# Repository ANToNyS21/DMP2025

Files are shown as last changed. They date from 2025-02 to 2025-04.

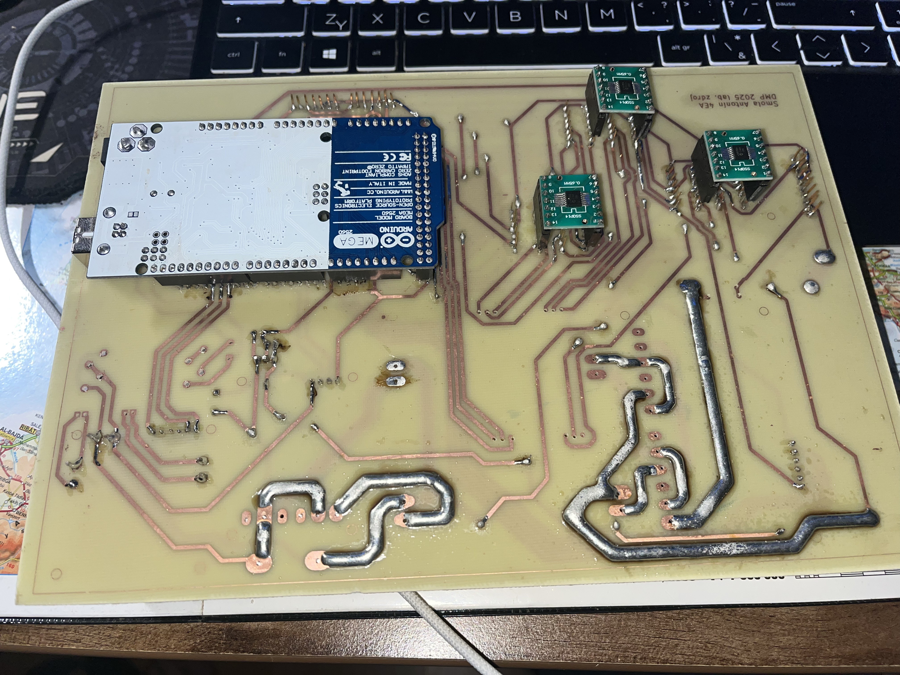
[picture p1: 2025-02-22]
smolaan21/media/DPS_testování_DCP2.JPG

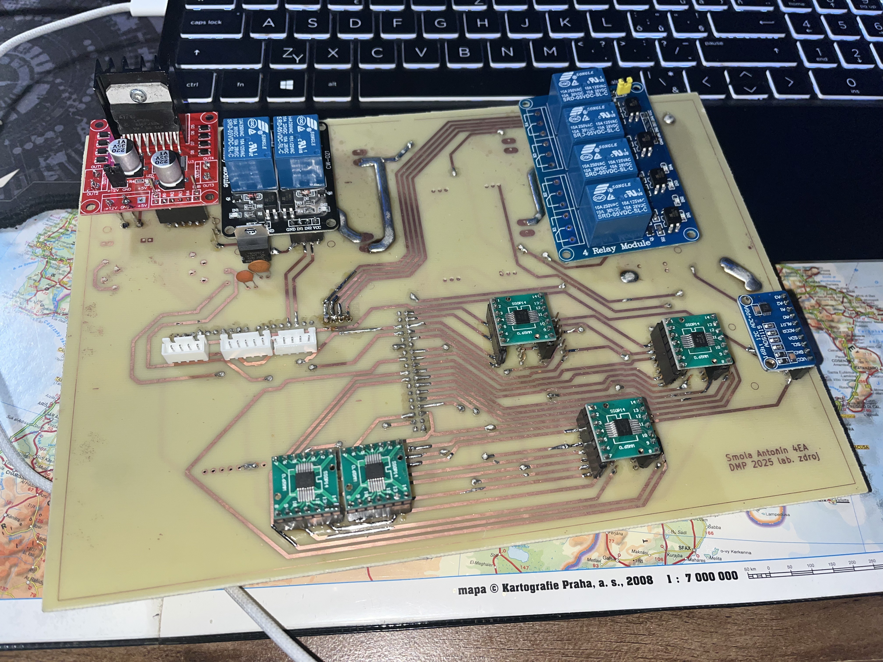
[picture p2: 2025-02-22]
smolaan21/media/DPS_testování_DCP1.JPG

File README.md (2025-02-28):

# DMP2025
sestava na ONSHAPE : https://cad.onshape.com/documents/a55f27827d7d0bf78ad17041/w/e62290534607ad3c1cca5b53/e/726e90d26969cd6e7ac2d84b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

video s funkčností / ukázkou menu:

https://drive.google.com/file/d/1NYgzzBReGRTbW6AwwNUOp2N6VFr0sSx1/view?usp=sharing

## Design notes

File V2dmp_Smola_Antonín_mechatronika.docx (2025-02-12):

Dlouhodobá maturitní práce

26-41-M/01 Elektrotechnika

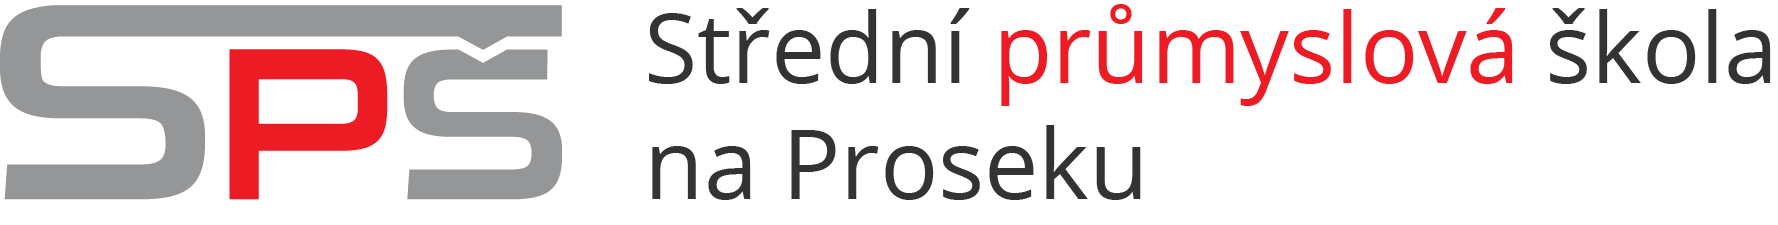
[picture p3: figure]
Logo

Laboratorní zdroj

Smola Antonín

Vedoucí: Jan Kárník

Zaměření: Mechatronika

2025

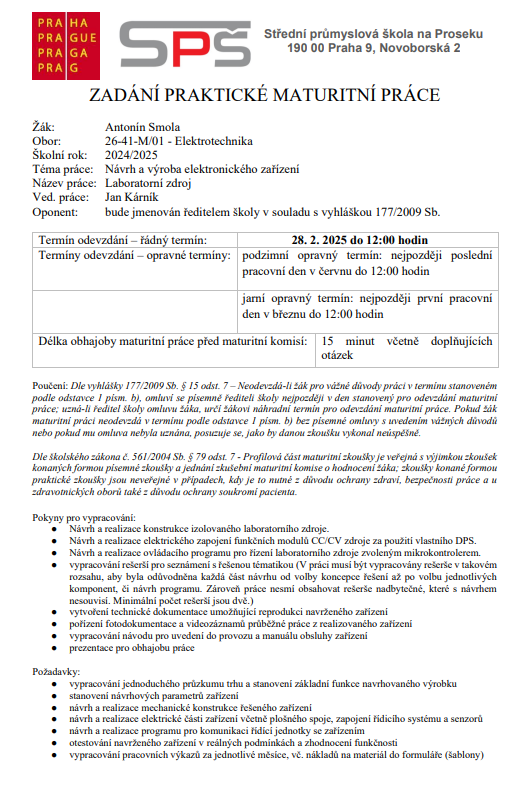
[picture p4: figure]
Obsah obrázku text, snímek obrazovky, Písmo, dopis Popis byl vytvořen automaticky
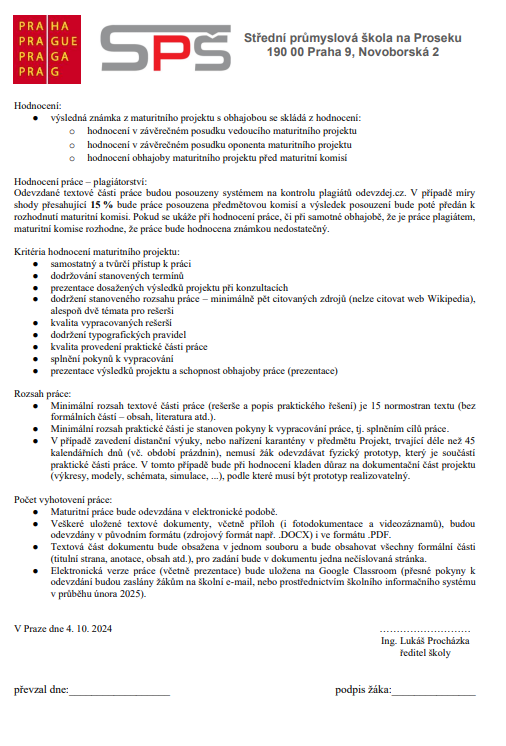
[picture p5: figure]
Obsah obrázku text, snímek obrazovky, dokument, dopis Popis byl vytvořen automaticky

# Prohlášení

Prohlašuji, že jsem svou maturitní práci vypracoval samostatně a že jsem uvedl veškeré použité informační zdroje (literaturu, projekty, SW, atd.), které jsou uvedené v seznamu literatury.

Nemám závažný důvod proti užití tohoto školního díla ve smyslu § 60 zákona č. 121/2000 Sb., o právu autorském, o právech souvisejících s právem autorským a o změně některých zákonů (autorský zákon).

V Praze, 2025

……………………………………

Podpis autora práce

# Poděkování

Tímto bych rád poděkoval svým rodičům, kteří byli mou oporou při tvorbě dlouhodobé maturitní práce, po fyzické a abstraktní stránce. Rád bych také poděkoval všem učitelům, kteří mi s touto prací byly nápomocni a ochotni konzultovat problémy, spojené s touto prací, které jsem musel řešit .

# Abstrakt

CZ verze

# Abstract

EN verze

# Obsah

# Seznam obrázků

# Seznam tabulek

# Úvod

Cílem práce je návrh a realizace digitalizace laboratorního zdoje. Tohoto cíle chci dosáhnout výměnou stávajících potenciometrů na modulu CC a CV za obvody, které převedou digitální výstup z mikrokontroleru, pomocí DA převodníků a operačních zesilovačů, na napětí které bude použito jako referenční napětí na modulu CC, CV.

V poslední době jsem se začal zajímat o funkcionalitu laboratorních zdrojů, protože po koupi komerčně dostupného laboratorního zdroje jsem se jím rychle stal fascinován. Na tomto zdroji mi ale nevyhovuje uživatelské rozhraní v podobě dvou potenciometrů a špatně nečitelného displeje. Chtěl bych tyto chyby opravit ve své práci v podobě enkodérů jako uživatelské rozhraní a 20x4 LCD displejem.

Práce se bude skládat ze základní dekonstrukce laboratorního zdroje, pochopení funkcionality modulu CC a CV, vybrání nejoptimálnější digitalizační metody, návrh DPS, návrh schránky pro zdroj.

# Rešerše

(1)(2)(3)(4)(5)(6)(7)(8)(9)(10)(11)(12)(13)(14)(15)(16)

## 1.1 „Digitalizace“ potenciometrů

Na modulech CC a CV jsou 2 potenciometry o hodnotách 2KΩ, na nastavení výstupního proudu, a 50KΩ na nastavení výstupního napětí. Ty bych chtěl nahradit/upravit tak, aby šlo moduly ovládat přes enkodéry a mikrokontroler. Tuto rešerši jsem tedy věnoval vhodné náhražce 2 potenciometrů.

### 1.1.1 Digitální potenciometr (Digitally controlled potentiometer, DCP)

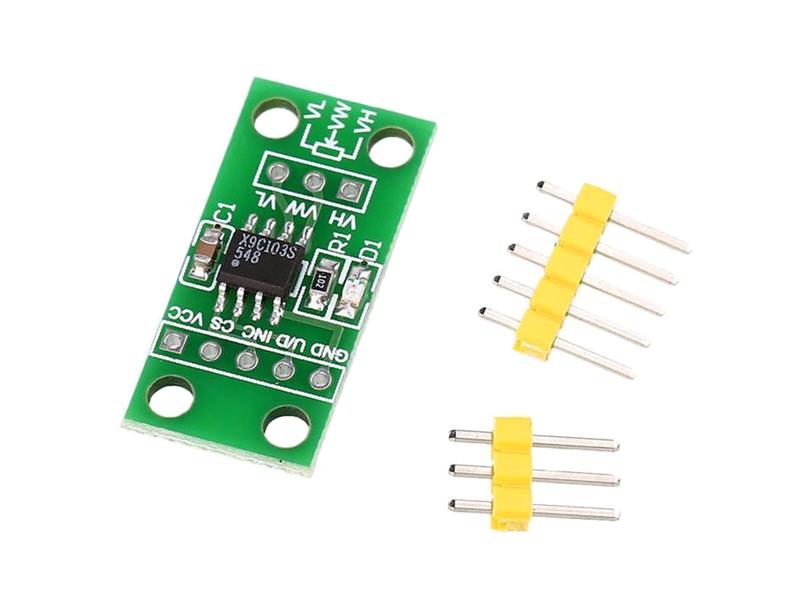
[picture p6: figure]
Digitální potenciometr 10kohm, modul s X9C103S

Popis: Digitální potenciometr (Obrázek 1), často označovaný jako DCP, funguje jako náhrada klasického mechanického potenciometru, ale místo manuálního otáčení rotační hřídelí je odpor nastavován pomocí digitálních signálů na logických úrovních. Tento typ potenciometru využívá pevný rezistorový řetězec a elektronické přepínače, které selektivně propojují různé body na řetězci, tudíž na výstupu vzniká různý výsledný odpor.

Obrázek 1 – příklad DCP [1]

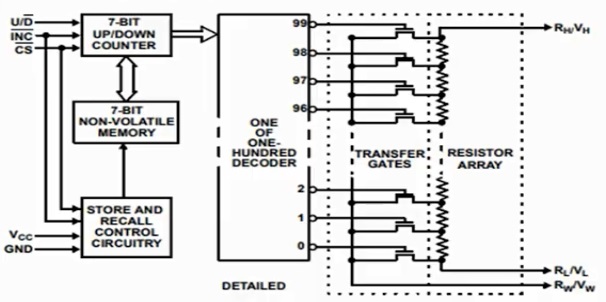
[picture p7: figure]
digital potentiometer x9c103s

Fungování: Ovládání digitálních potenciometrů probíhá prostřednictvím komunikačních protokolů, jako jsou I2C a SPI. Z mikrokontroleru se po sběrnici odešle v požadovaném formátu, daným výrobcem DCP, informace o požadovaném počtu do série spojených pevných rezistorů(Obrázek 2Chyba! Nenalezen zdroj odkazů.). Mikrokontroler na DCP poté informace přijme, vyhodnotí a provede potřebné kroky pro splnění přijatých požadavků.

Obrázek 2 - vnitřní schema DCP [2]

Příklady použití: Digitální potenciometry lze využit, například při řízení hlasitosti ve zvukových systémech, nastavování napěťového offsetu, ladění frekvenčních filtrů nebo jako náhrada potenciometrů v určitých aplikací.

Výhody: Umožňuje přesné, rychlé řízení výstupu bez mechanického opotřebení a snadná integrace do digitálně řízených systémů.

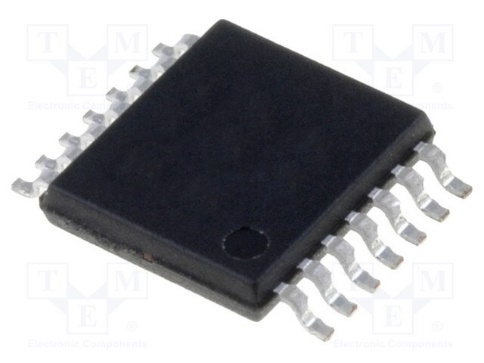
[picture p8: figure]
MICROCHIP TECHNOLOGY MCP41HV51-103E/ST - IC: číslicový potenciometr

Nevýhody: Nižší maximální výkony (např. některé jsou omezené na napětí v řádu několika mW výkonu nebo desítek mA proudu) a nižší maximální napětí.

Příklady součástek:

- MCP41010 (od Microchip, SPI rozhraní)
- MCP41HV51 (Obrázek 3) (od Microchip, SPI rozhraní)
- AD5252 (od Analog Devices, I2C rozhraní)

Obrázek 3 - MCP41HV51 [3]

### 1.1.2 Digitálně ovládané tranzistory (MOSFET)

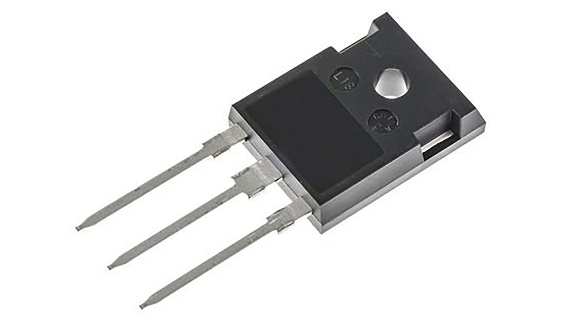
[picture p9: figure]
MOSFET C2M1000170D N-kanálový 5 A 1700 V, TO-247, počet kolíků: 3 Jednoduchý SiC

Popis: Tranzistory MOSFET (Obrázek 4) mohou regulovat proud a napětí pomocí pulzní šířkové modulace (PWM), kterou lze ovládat pomocí mikrokontroleru.

Fungování: Průměrné výstupní napětí nebo proud lze řídit PWM signálem, jehož frekvence a střída určuje hodnotu výstupního signálu. PWM signál vytváří zátěž, která prochází tranzistorem, čímž se mění průměrné napětí.

Obrázek 4 – MOSFET [4]

Výhody: Vysoká účinnost.

Nevýhody: Složitější implementace a požadavek na vyhlazovací obvody a neschopnost plynulé regulace (bez vyhlazovacího obvodu na výstupu skoky napětí)

### 1.1.3 Digitální řízení přes DAC (Digital-to-Analog Converter)

Popis: DAC převádí digitální hodnoty z mikrokontroléru na čisté analogové napětí. To nahrazuje funkci potenciometru pro jemné nastavování referenčního napětí či proudového řízení.

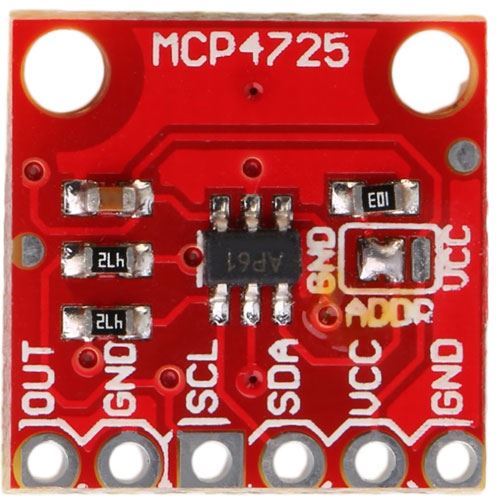
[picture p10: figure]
DAC převodník 12Bit I2C s MCP4725 : H A D E X , spol. s r.o.

Fungování: Mikrokontrolér posílá digitální data do DAC, který je převádí na analogové napětí.

Obrázek 5 - MCP4725 [5]

Výhody: Vysoká přesnost, široký rozsah aplikací.

Nevýhody: Vyšší náklady a složitost v porovnání s digitálním potenciometrem.

Příklady DAC:

- MCP4725 (Obrázek 5) (jednokanálový, I2C rozhraní)
- AD5686 (čtyřkanálový, SPI rozhraní)

### 1.1.4 Přímé řízení pomocí PWM a nízkoprůchodového filtru

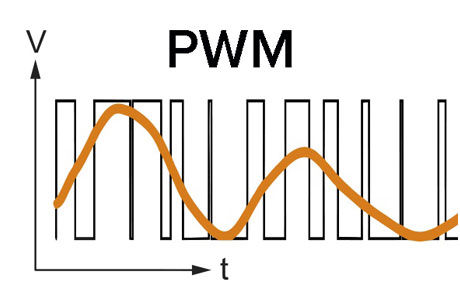
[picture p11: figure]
What Is PWM (Pulse Width Modulation)? | IndMALL

Popis: Alternativním způsobem pro dosažení analogového výstupního napětí je použití PWM signálu z mikrokontroléru. Tento signál je filtrován pomocí nízkoprůchodového filtru, který vyhlazuje výstup na plynulý analogový signál.

Obrázek 6 – PWM [6]

Fungování: PWM signál prochází nízkoprůchodovým filtrem, který eliminuje vyšší frekvence a zachovává průměrnou hodnotu signálu (Obrázek 6). To umožňuje převod PWM signálu na přijatelný analogový.

Výhody: Snadná integrace s Arduino a jinými mikrokontroléry.

Nevýhody: Nutnost navrhnout vhodný filtr a nižší přesnost ve srovnání s DAC nebo digitálním potenciometrem, vysoké proudové zatížení mikrokontroleru.

### 1.1.5 Závěr rešerše a moje volba

Pro mojí aplikaci na modulech CC a CV jsem si vybral požít digitální potenciometry MCP41HV51 (od Microchip, SPI rozhraní), protože přímo nahradí potenciometr bez nutnosti použití složitých obvodů na ovládáni např. DAC a operačních zesilovačů. Nevýhodou jsou fixní hodnoty možného odporu v mém případě MCP41HV51 je 8 bitový digitální potenciometr s 256 možnými hodnotami odporu.

## 1.2 Měření proudu na výstupu zdroje

V mém projektu potřebuji na výstupu zdroje měřit výstupní proud, jehož hodnotu potřebuji zobrazovat na displeji. Potřebuji tedy nějakou metodu, která dokáže změřit proud a odeslat jeho hodnotu do mikrokontroleru.

### 1.2.1 Měření proudu pomocí shunt rezistoru

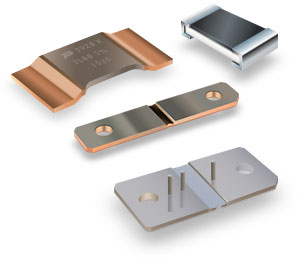
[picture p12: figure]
prodline_current_sense_resistors_lg

Jednou z nejběžnějších metod měření proudu je použití shunt rezistoru (Obrázek 7). Tato metoda je založena na Ohmově zákonu, který říká, že proud (I) je přímo úměrný napětí (U) a nepřímo úměrný odporu (R), tedy

Obrázek 7 - Shunt rezistor [7]

| I=U/R | (2.1)

V tomto případě je malý odpor (shunt rezistor např. 1Ω) vložen do série s obvodem, ve kterém chceme měřit proud. Napěťový úbytek na tomto odporu je měřen pomocí ADC (analogově-digitálního převodníku) a následně odeslán do mikrokontroleru.

Výhody: Jednoduché zapojení, přesné přímé měření, široký rozsah měření při různých hodnotách proudu.

Nevýhody: Shunt rezistor způsobuje úbytek napětí v obvodu, zahřívání rezistoru při vyšších proudech může ovlivnit přesnost měření, nutnost používat výkonové shunt rezistory

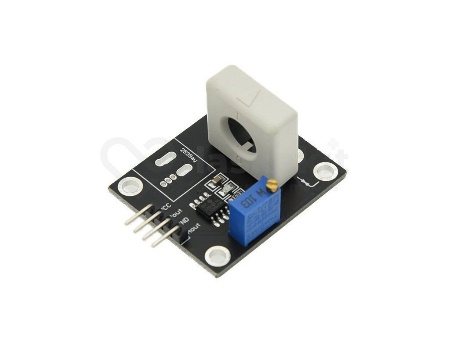
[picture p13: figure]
Hallův neinvazivní snímač proudu WCS1800-35A

### 1.2.2 Hallův efekt

Měření proudu pomocí Hallova efektu je nepřímá metoda, která využívá vlivu magnetického pole na polovodičový materiál. Když proud prochází vodičem, vytváří kolem něj magnetické pole. Hallův snímač (Obrázek 8) umístěný v blízkosti vodiče měří toto pole.

Obrázek 8 - Hallův snímač proudu [8]

Výhody: Nepřímé bezpečné měření, protože není třeba zasahovat přímo do obvodu, žádné úbytky napětí v měřeném obvodu, vhodné pro měření jak stejnosměrného (DC), tak střídavého (AC) proudu.

Nevýhody: Nižší přesnost než u přímých metod, vyšší cena snímačů, citlivost na vnější magnetická pole, což může způsobit rušení.

### 1.2.3 Transformátor proudu

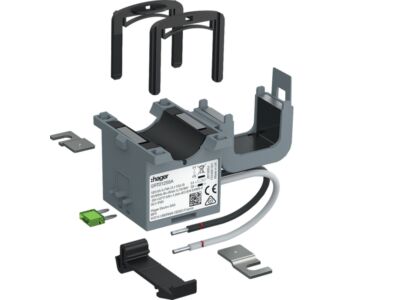
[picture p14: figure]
Proudový transformátor s děleným jádrem

Transformátory proudu (CT, Current Transformer,Obrázek 9) jsou speciální typy transformátorů určené pro měření vysokých proudů ve střídavých obvodech. Primární vinutí transformátoru je vodič s měřeným proudem, zatímco sekundární vinutí je připojeno k měřicímu přístroji, kde proud snížený poměrem transformace může být bezpečně měřen AD převodníkem.

Obrázek 9 - proudový transformátor [9]

Výhody: Možnost měřit vysoké proudy, elektrické oddělení mezi primární a sekundární stranou, široký rozsah měření.s

Nevýhody: Použitelné pouze pro střídavé proudy, vyžaduje přesnou kalibraci, aby byla zachována přesnost, složitější mechanická konstrukce.

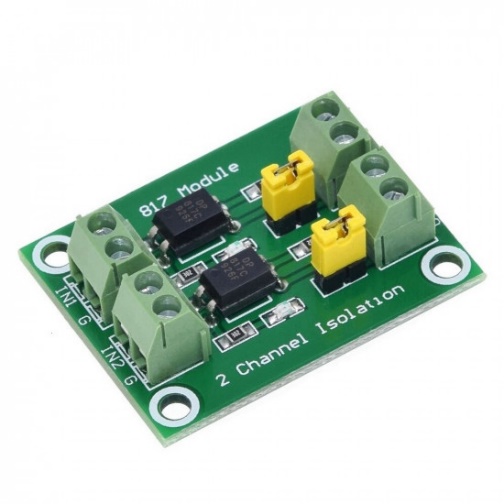
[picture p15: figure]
Dvoukanálový modul optoizolátoru s PC817

### 1.2.4 Měření proudů pomocí optoizolátorů

Optoizolátory (Obrázek 10) se často používají k měření proudu v prostředích, kde je třeba galvanické oddělení. Tento princip zahrnuje použití LED a fotodetektoru – proud protékající obvodem způsobí, že LED emituje světlo, které je detekováno fotodetektorem a převedeno na elektrický signál úměrný proudu.

Výhody: Úplné galvanické oddělení mezi měřeným obvodem a měřicím zařízením, vysoká bezpečnost při měření vysokých proudů nebo napětí.

Obrázek 10 - dvoukanálový optoizolátor [10]

Nevýhody: Komplexní elektronika potřebná pro zpracování signálu, omezený rozsah a přesnost měření.

## 1.3 Závěr rešerše a moje volba

Pro moji aplikaci nemohu použít metody pro měření proudů v AC obvodu bez dalších DC to AC převodníků, proto Transformátor proudu nelze použít. Vzhledem k nízkým měřeným proudům a možnosti rušení Hallova sensoru díky kompaktním požadavkům laboratorního zdroje. Pro moji aplikaci tedy použiji metodu Shunt rezistoru a AD převodníku, protože v kombinaci s 12bitovým AD převodníkem, dokáži dosáhnou velmi přesného měření proudu s minimální nepřesností díky přímému měření proudu, které tato metoda zahrnuje.

# Návrhové parametry

Laboratorní zdroj s CC a CV (dále jen „Laboratorní zdroj“) bude konstruován jako relativně přenosný (bez madel, pouze jeho rozměry a váha by měly umožnit jeho přesun) a s elektricky izolovanými výstupy od přívodního AC napětí. Laboratorní zdroj bude mít v zadní části konektor 3 Pin IEC320 C14 s integrovaným kolébkovým vypínačem a pojistkou. Všechny kovové části zdroje budou elektricky spojeny s ochranným vodičem (PE). Zdroj bude na přední straně disponovat 3 výstupními terminály: MÍNUS, GND, PLUS (v tomto pořadí) (GND bude spojeno s PE ochranným vodičem), displejem a dvěma enkodéry jako uživatelské rozhraní.

Laboratorní zdroj bude na displeji zobrazovat aktuální výstupní napětí a výstupní proud zdroje, které se budou upravovat po stisku jednoho z enkodérů podle požadavků uživatele. Laboratorní zdroj bude schopen dodávat napětí až 30V a proud až 4A.

# Praktická část

V následujících kapitolách jsem se zaměřil na praktickou část DMP, zvažování možných řešení, odůvodnění mnou vybraného řešení a následné provedení tohoto řešení v praxi.

## 1.4 Elektrická část

### 1.4.1 CC a CV moduly

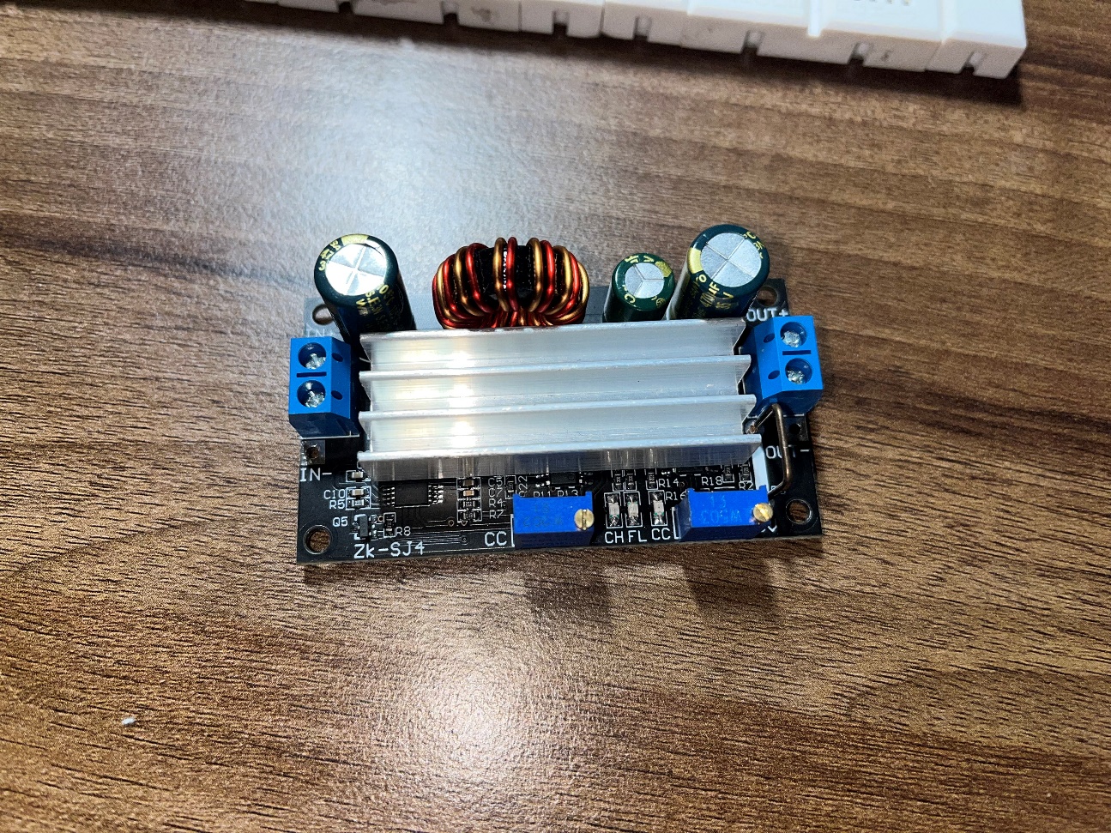
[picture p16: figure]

Hlavní částí mého maturitního projektu jsou dva zdroje napětí a proudu (Obrázek 11) s možností regulace těchto veličin podle polohy dvou trimerů. Trimer 50KΩ na regulaci výstupního napětí a trimer 2KΩ na regulaci výstupního proudu. Tyto trimery nahrazuji jejich digitálními variantami DCP (1.1.1).

Obrázek 11 - modul ZK-SJ4

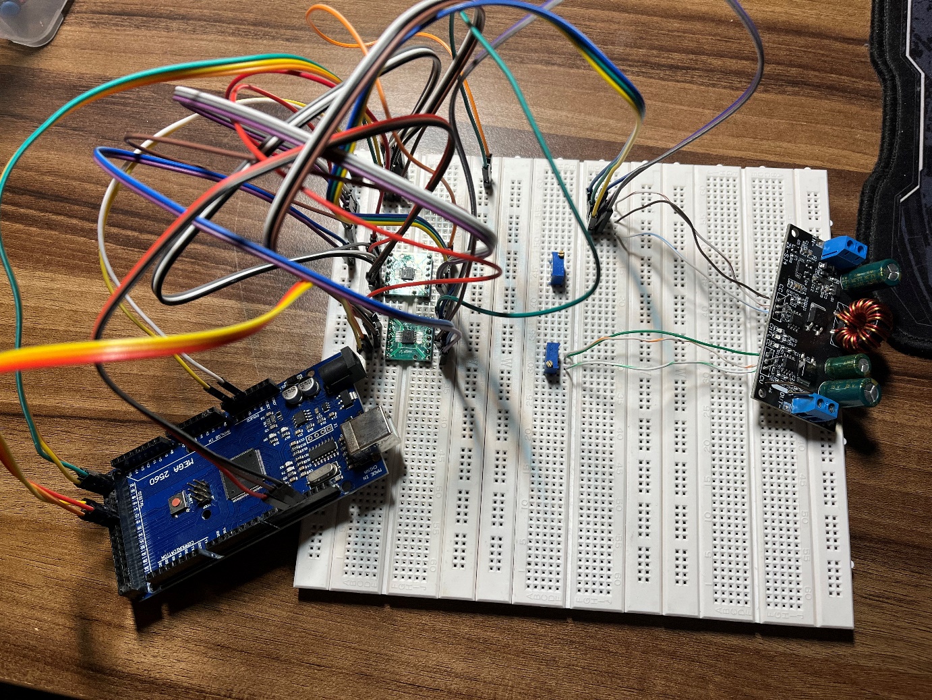
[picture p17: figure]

Pro usnadnění testovaní možných nahrazení trimerů jsem u modulu napětí a proudu odstranil oba trimery a nahradil je drátovými propojkami pro snadnou integraci do nepájivého pole (Obrázek 12).

Obrázek 12 - prototypové zapojí modulu s dvěma DCP

Jako první variantu jak ovládat proud a napětí modulů zdrojů jsem zkoušel využít DCP
X9C103S (Obrázek 1), který podle datasheatu ([14]) dokázal nastavit 100 různých hodnot odporu mezi jeho maximální a minimální, hodnotou podle následujícího vzorce

[3.1.1]

R_V =(R_(MAX))/100×STEP ,

Kde R_V představuje výstupní hodnotu odporu DCP, R_(MAX) maximální hodnotu odporu DCP a STEP představuje nastavený krok v celých číslech na DCP od 0 do 99.

Pomocí knihovny FastX9CXXX [12] poté DCP lze jednoduše ovládat a získat i přibližnou hodnotu výstupního odporu.

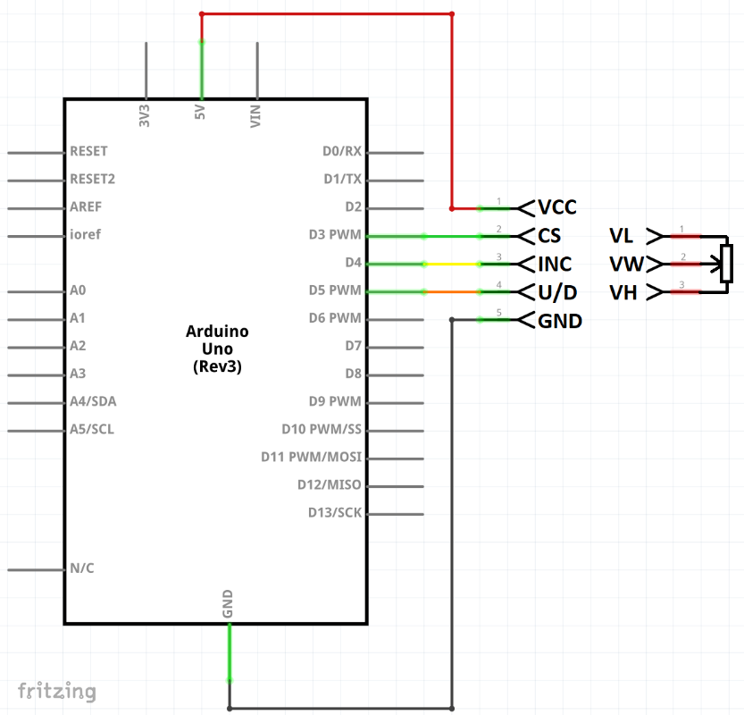
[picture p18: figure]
Digitální potenciometr X9C103S schéma

Tento způsob ovládání vyžaduje pouze 5 propojení DCP s mikrokontrolerem, přičemž piny 1 a 5 jsou použity pro napájení a zbylé piny 2, 3, 4 musí být připojeny na digitál out piny mikrokontroleru. Bohužel DCP X9C se vyrábí pouze ve variantách 1KΩ, 10kΩ,
100kΩ, což pro mé účely bylo značně nepraktické, protože pro docílení potřebného odporu by bylo zapotřebí využívat paralelního zapojení výstupů DCP pro dosáhnutí požadovaného odporu na výstupu.

Obrázek 13 - zapojení X9C102S s Arduinem UNO [11]

Další z problémů, kvůli kterému jsem se definitivně rozhodl toto řešení pomocí
DPC X9C zavrhnout, byla limitace napětí stanovená výrobcem [13], které může být od –8V do +8V mezi VL a VH (Obrázek 13). Toto byl zásadní parametr, protože moduly CC a CV mají na pinech trimerů napětí až +28V při maximálním zatížením. Z tohoto důvodu jsem jako jednu z hlavních kategorií pro výběr jiného DCP vybral maximální napětí na výstupních pinech.

Jako mé další a zároveň finální řešení řízení modulů CC a CV jsem zvolil použití DCP MCP41HVX1. Už z jejich názvu (HV- High Voltage) je patrná jejich hlavní výhoda a to maximální napětí na výstupních pinech až +36V nebo ±18V, což bylo ideální pro mou aplikaci +28V. Další výhodou těchto DCP je širší rozsah možných hodnot oproti 100 možných pozic MCP41HVX1 má 256 možných pozic.

Těchto 256 pozic navíc mi umožnilo ovládání napětí na přesnost 0,125V oproti předchozímu teoretickému 0,32V na jeden STEP podle rovnice

[3.1.2]

V_(STEP) =(V_(Max))/(STEPS) , kdy V_(STEP) je napětí na 1 krok, V_(Max) je maximální napětí modulu CC a CV, a STEPS je počet kroků DCP.

Bohužel ale MCP41HVX1 vyžaduje pro své ovládání využití SPI komunikačního protokolu a připojení 8mi pinu na mikrokontroler pro úspěšné ovládání. Navíc podle výrobce [15] MCP41HVX1 potřebuje pro svou správnou funkčnost ČÍSTÉ analogové napětí +30V, které musí být dodáno z externího zdroje. Naštěstí +30V je zapotřebí pouze jako reference pro funkčnost analogového obvodu v DCP a reálný odběr je okolo 8mA na modul DCP, proto stačí použít měkčí zdroj napětí.

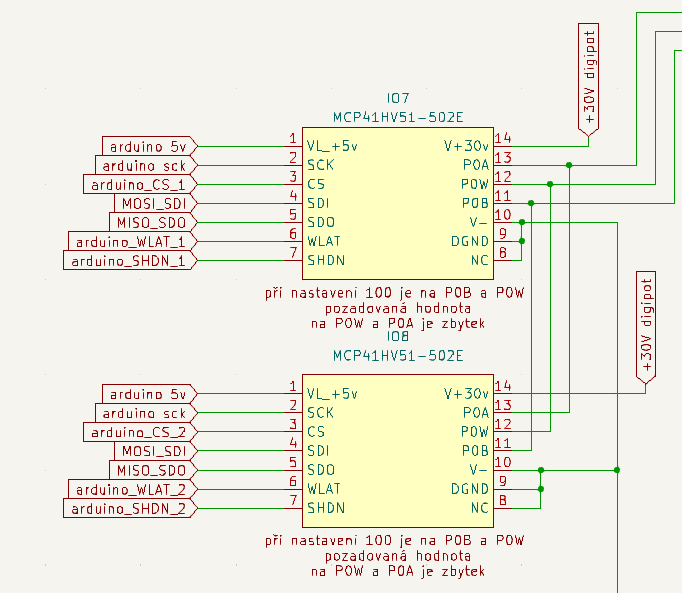
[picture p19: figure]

Pro mé účely jsem použil vždy pár MCP41HVX1 se stejnou hodnotou odporu zapojený do paralelního zapojení (Obrázek 14). Tímto zapojením jsem také docílil podle rovnice [3.1.2] až 32768 možných nastavení výstupního napětí modulů s přesností cca na 0,001V.

Obrázek 14 - zapojení MCP41HVX1

### 1.4.2 Schéma zapojeni

Mnou navržený obvod pro ovládání a propojení jednotlivých komponentů s mikrokontrolerem jde rozdělit na několik hlavních částí, jmenovitě na:

- Externí zdroj 12V
- On-board zdroje 5V a 36V
- Ovládání ventilátorů
- UI
- Měření výstupních veličin
- Jednotlivé CC a CV moduly a jejich DCP

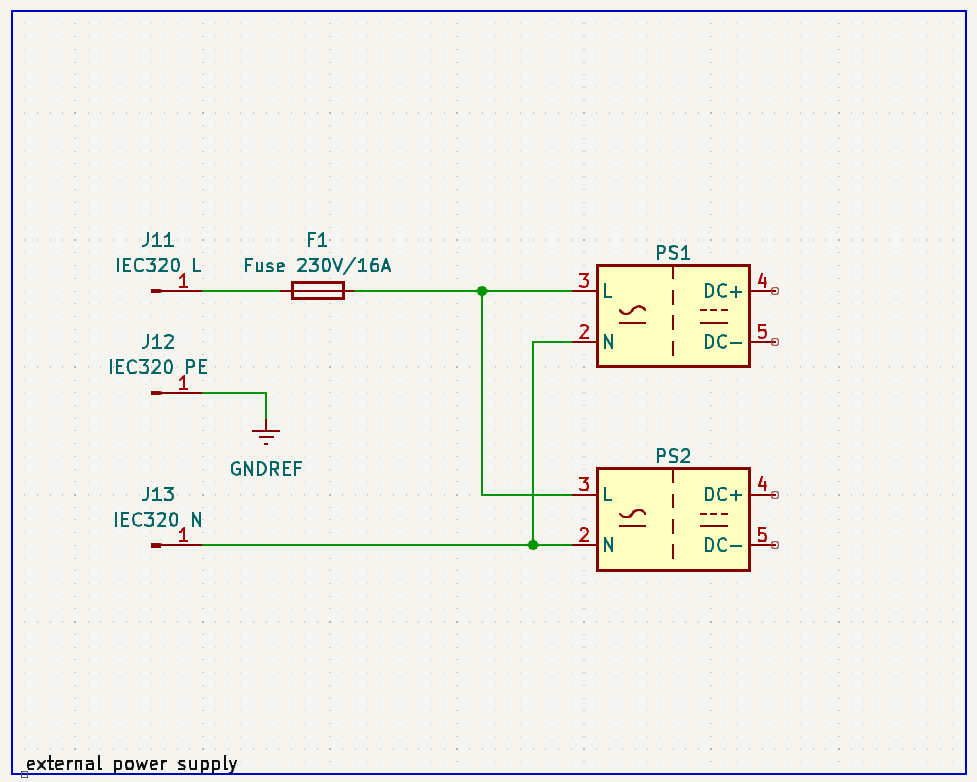
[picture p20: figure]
Obsah obrázku text, diagram, snímek obrazovky, Obdélník Obsah vygenerovaný umělou inteligencí může být nesprávný.

#### 1.4.2.1 Externí zdroj 12V

Obrázek 15 - 12v Power Supply

Pro hlavní napájení mého maturitního projektu jsem si vybral dva 250w zdroje z 230v AC na 12V DC (17). Pro přívod napájení do útrob maturitního projektu jsem vybral IEC320 C14 s integrovaným kolébkovým vypínačem a pojistkou, což řeší jištění systému a zároveň jeho zapínání a vypínání.

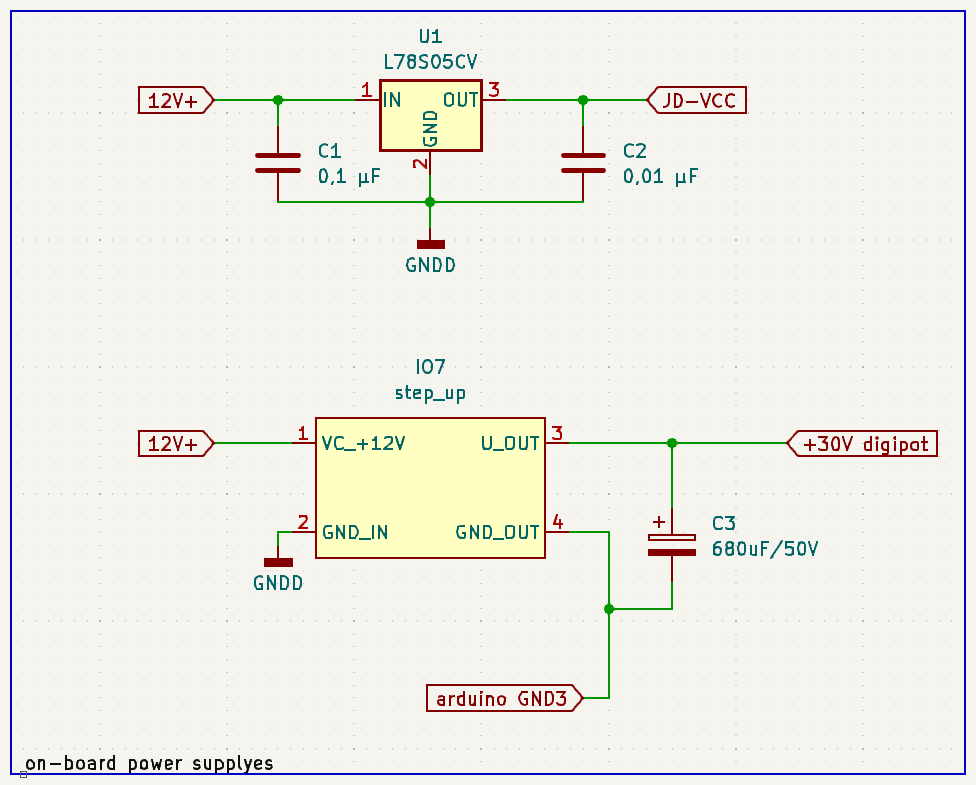
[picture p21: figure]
Obsah obrázku text, diagram, snímek obrazovky, Plán Obsah vygenerovaný umělou inteligencí může být nesprávný.

#### 1.4.2.2 On-board zdroje 5V a 36V

Obrázek 16 - On-board zdroje

Pro napájení relé logiky jsem vybral Linearní Stabilizátor napětí L78S05CV, který dokáže dodávat až 2A při 5V s použitím chladiče (18). V mém testovaní při sepnutí všech relé na DPS 5V obvod odebíral nejvíce 950mA, ale tento stav nemůže v reálnem provozu nikdy nastat z důvodu vzniku zkratu v obvodu. Nehledě na max. 950mA jsem L78S05CV vybavil chladičem a součástku umístil v průtoku vzduchu k ventilátoru pro zvýšení životnosti.

Pro napájení DCP analogových obvodů jsem vybral Modul DC/DC měnič step-up 5-40V/2A (19) s řídícím čipem LM2577. Tento měnič napájí jednotlivé DCP 32V. Jeho zatížení je při provozu prakticky nulové reálný odběr se pohybuje kolem 80mA.

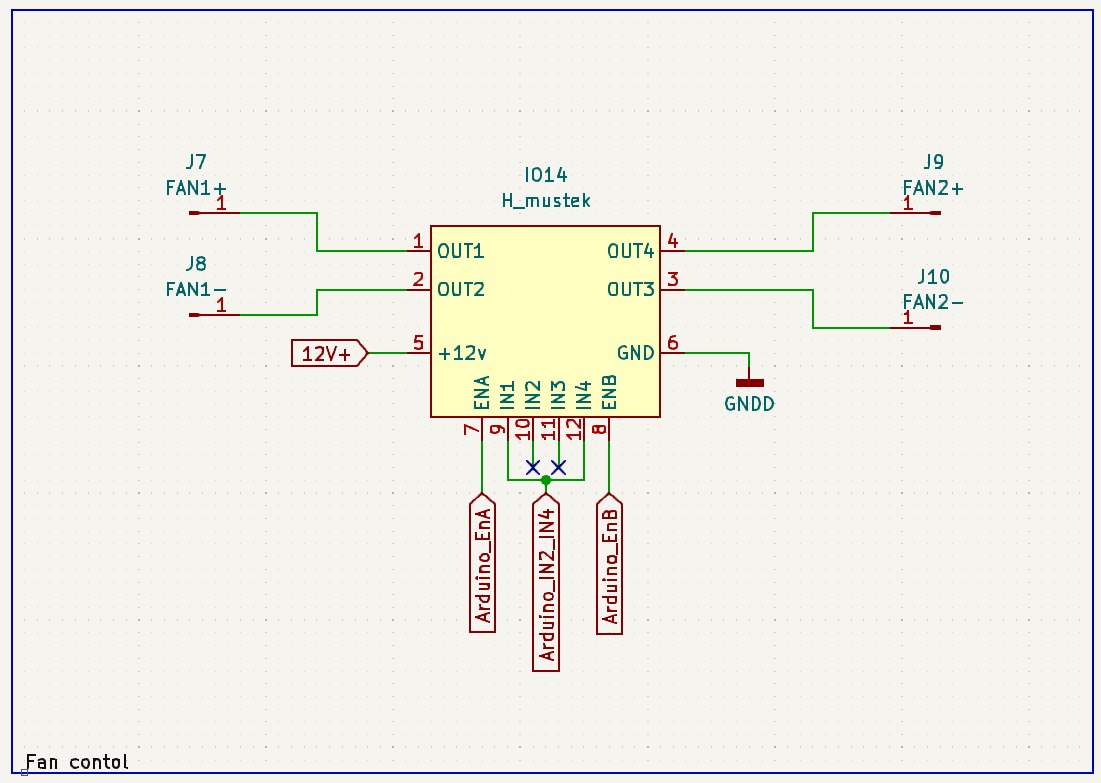
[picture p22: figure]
Obsah obrázku text, diagram, snímek obrazovky, Plán Obsah vygenerovaný umělou inteligencí může být nesprávný.

#### 1.4.2.3 Ovládání ventilátorů

Obrázek 17 - Ovládání ventilátorů

Pro ovládání rychlosti dvou ventilátorů jsem se rozhodl pro dvou kanálový Modul 2x H-můstek s L298N. Modul jsem do DPS zakomponoval v zapojení při kterém nejde mikrokontrolerem měnit směr otáčení ventilátorů, namísto toho lze pomocí PWM signálu ovládat rychlost otáček jednotlivých ventilátorů a zapnout nebo vypnout oba ventilátory.

V retrospektivě bych ovládání ventilátorů příště vyřešil pomocí tranzistorů, nebo pomocí ventilátorů s podporou PWM ovládání otáček přímo zabudované do ventilátorů.

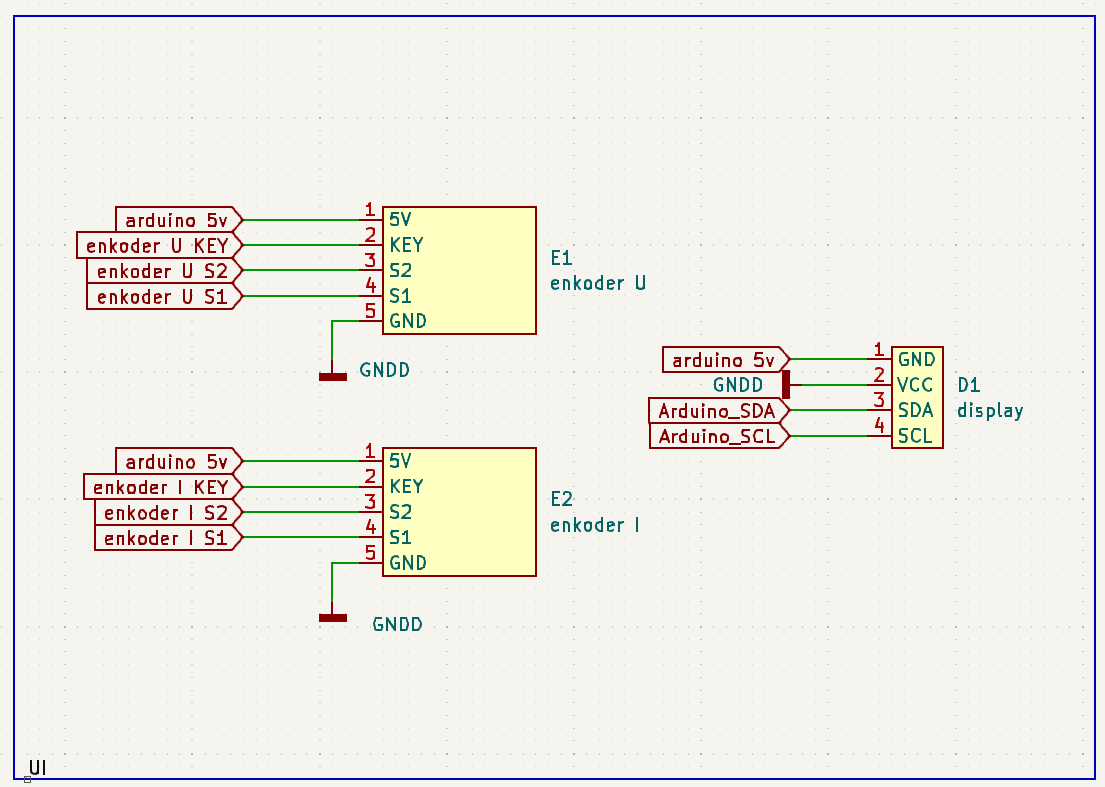
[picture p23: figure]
Obsah obrázku text, snímek obrazovky, diagram, řada/pruh Obsah vygenerovaný umělou inteligencí může být nesprávný.

#### 1.4.2.4 UI

Obrázek 18 - UI zapojeni

Pro komunikaci mezi zařízením a uživatelem jsem vybral 20x4 LCD display s I2C adaptérem pro snadnou implementaci do mého projektu

Dále pak pro komunikaci mezi uživatelem a zařízením jsem zvolil dva enkodéry s možnosti stisku pro potvrzeni vstupu od uživatele. Jeden enkodér slouží pro nastavování výstupního napětí a druhý pro nastavování výstupního proudu

# Závěr

V závěru autor zhodnocuje

# Zdroje

Obrázky:

[1] https://www.hadex.cz/m496-digitalni-potenciometr-10kohm-modul-s-x9c103s/
[2] https://www.researchgate.net/figure/X9C103-Block-diagram_fig1_348463410
[3] https://www.tme.eu/cz/details/mcp41hv51-103e_st/potenciometry-digitalni/microchip-technology/
[4] https://cz.rs-online.com/web/p/mosfet/1258047
[5] https://www.hadex.cz/m437h-dac-prevodnik-12bit-i2c-s-mcp4725/
[6] https://www.thomsonlinear.com/en/support/tips/what-is-pwm
[7] https://www.bourns.com/de/products/resistors/current-sense-resistors
[8] https://www.laskakit.cz/halluv-neinvazivni--snimac--proudu-wcs1800-35a/
[9] https://www.elfetex.cz/proudovy-transformator-s-delenym-jadrem-3200235
[10] https://pajenicko.cz/dvoukanalovy-modul-optoizolatoru-s-pc817
[11] https://navody.dratek.cz/navody-k-produktum/digitalni-potenciometr-x9c103s.html
[12] https://github.com/GitMoDu/FastX9CXXX
[13] https://www.elecrow.com/download/X9C103S_Datasheet.pdf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
[14] https://www.hadex.cz/spec/m496.pdf
[15] https://ww1.microchip.com/downloads/en/devicedoc/20005207b.pdf

Rešerše Literatura použitá k posouzení nejlepšího řešení pro moji aplikaci:

(1) https://vyvoj.hw.cz/zaklady-digitalnich-potenciometru-a-jak-je-pouzivat.html
(2) https://shop.atoselektro.cz/digitalni-potenciometr-10kohm-modul-s-x9c103s_d486842.html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
(3) https://www.electroniclinic.com/digital-potentiometer-x9c103s-arduino-circuit-and-programming/
(4) https://www.tme.eu/cz/details/mcp41hv51-103e_st/potenciometry-digitalni/microchip-technology/
(5) https://cz.rs-online.com/web/p/mosfet/9047345
(6) https://www.youtube.com/watch?v=uezoQ5fkixY
(7) https://www.digikey.cz/cs/products/filter/%C5%99%C3%ADzen%C3%AD-spot%C5%99eby-energie-pmic/regul%C3%A1tory-nap%C4%9Bt%C3%AD-ovlada%C4%8De-line%C3%A1rn%C3%ADch-regul%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
(8) https://www.ziehl-abegg.com/cs/produkty/elektronicke-pristroje-pro-regulaci-napeti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
(9) https://www.hadex.cz/m437h-dac-prevodnik-12bit-i2c-s-mcp4725/
(10) https://botland.cz/blog/mosfet-co-to-je-a-k-cemu-slouzi/
(11) https://www.indmall.in/faq/what-is-pwm-pulse-width-modulation/
(12) https://www.researchgate.net/figure/X9C103-Block-diagram_fig1_348463410
(13) https://vyvoj.hw.cz/presne-mereni-proudu-a-rizeni-vykonu-pomoci-shunt-rezistoru.html
(14) https://cs.wikipedia.org/wiki/Hall%C5%AFv_jev
(15) https://www.riacontrol.cz/slovnicek/halluv-efekt/
(16) https://www.hangzhiprecision.com/cs/znalostni-centrum/hall-efekt-proud-senzor/
(17) https://www.toplux.cz/vnitrni/05205/
(18) https://img.gme.cz/files/eshop_data/eshop_data/3/330-018/dsh.330-018.1.pdf
(19) https://img.gme.cz/files/eshop_data/eshop_data/10/774-014/dsh.774-014.1.pdf

zapojení relátek:

https://electronics.stackexchange.com/questions/667487/switching-between-series-and-parallel-connection-of-batteries-using-relays

# Příloha A

Do příloh autor řadí veškeré obrázky, grafy, tabulky, výpočty a schémata, které nemohl z důvodu velikosti či rozsahu umístit přímo do práce. V práci se tak objeví jen část (např. základní vzorec a výsledek) a zbytek umístí do přílohy. Přílohy se nečíslují. Každá příloha se označuje písmenem A, B, C, D, E… nebo římskými číslicemi I, II, III, IV, V…

Pokud chcete do přílohy vložit zdrojový kód, tak nejlépe jako obrázek z programovacího prostředí. Pokud byste rádi vložili kód jako prostý text, dbejte na to, aby kód nesl vhodné formátování a byl vhodně strukturován. Viz příklad níže. Jako styl textu využijte → Program.

int main() {

srand(time(0));

int number = generate_random();

int user_number = 0;

int count = 0;

printf("Zadejte číslo: ");

while (true) {

scanf("%d", &user_number);

count++;

if (user_number > number) {

printf("Zadejte menší číslo: ");

}

else if (user_number < number) {

printf("Zadejte větší číslo: ");

}

else {

printf("Gratuluji uhold jste číslo | %d |.

Počet pokusů | %d |.\n", number, count);

break;

}

}

return 0;

}

# Příloha B

Zde můžete vložit dokumentaci DPS.

# Příloha C

Zde můžete vložit schéma elektrického zapojení.

# Příloha D

Zde můžete vložit 3D model Vašeho projektu.

Praktická část

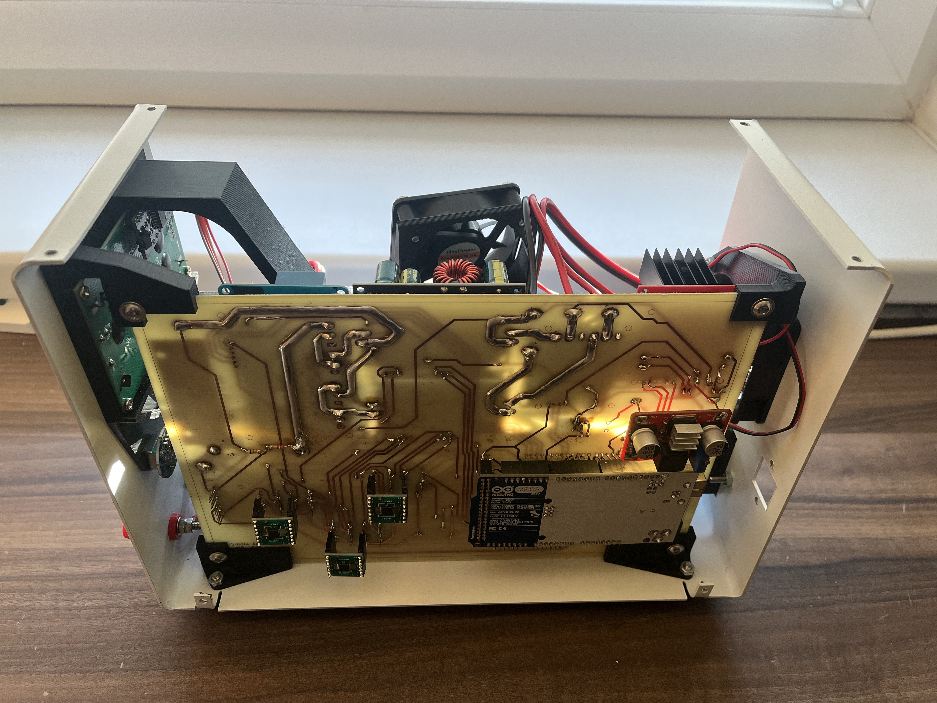
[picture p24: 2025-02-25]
smolaan21/media/finálně_osazená_schránka2.jpeg

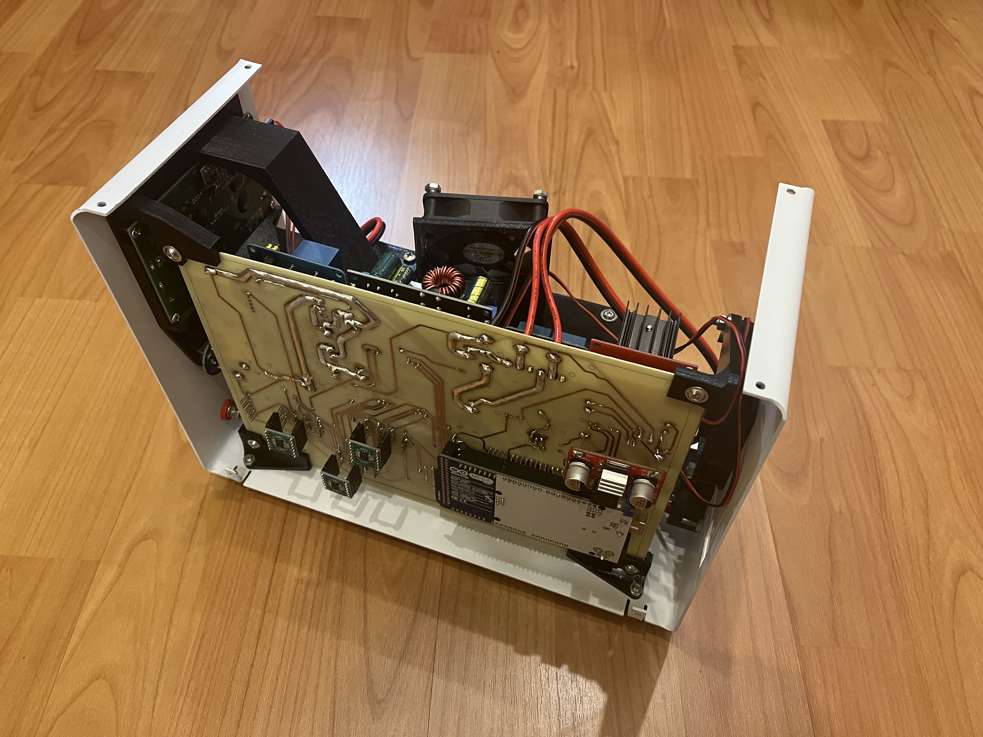
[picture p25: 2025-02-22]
smolaan21/media/DPS_ve_schránce2.jpg

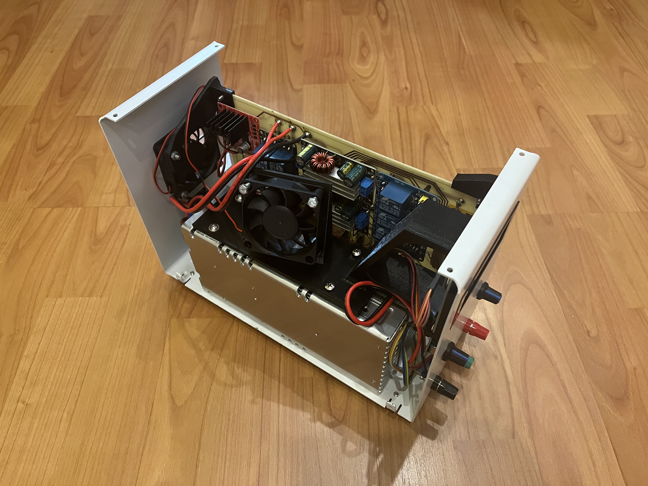
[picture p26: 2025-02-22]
smolaan21/media/DPS_ve_schránce1.jpg

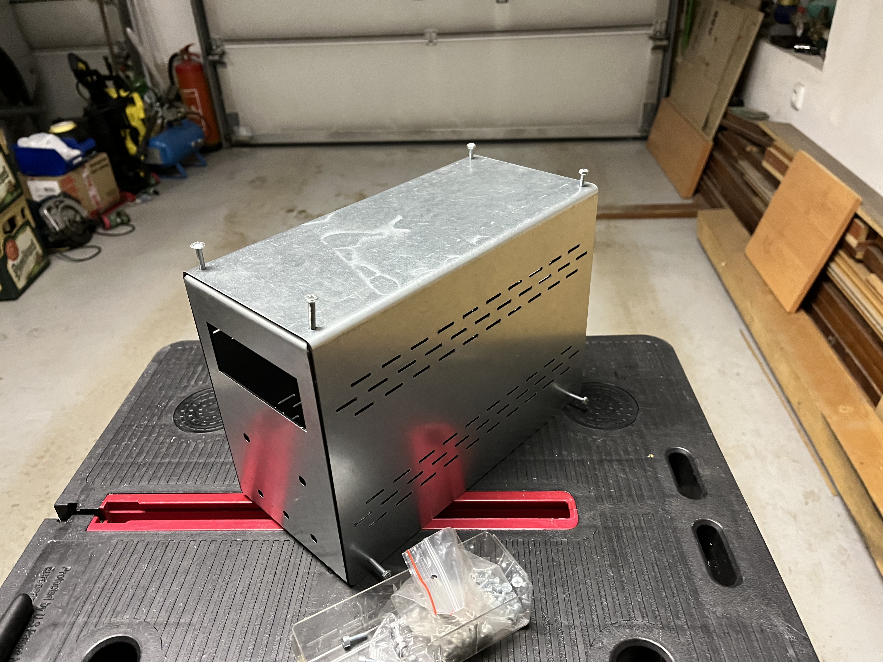
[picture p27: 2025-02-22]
smolaan21/media/naohýbaná_schránka3.jpeg

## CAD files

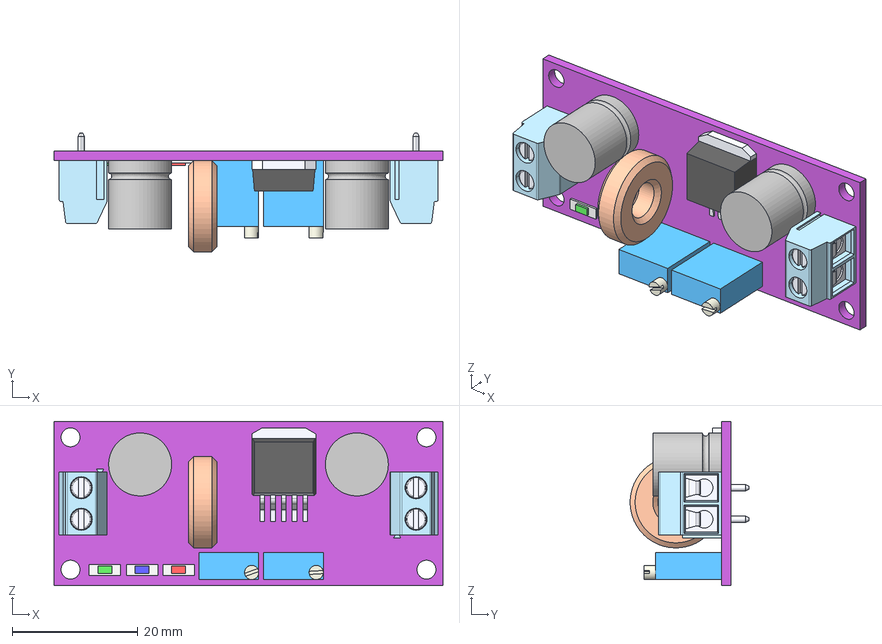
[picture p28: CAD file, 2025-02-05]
knihovna_kicad/Smola_dmp/Fuente DC-DC XL4015.step
61.8 x 18.8 x 26.1 mm
Board
Toroide
Pote VR
Pote CR
Capacitor 01
Capacitor 02
Bornera Salida
Bornera Entrada
XL4015
Led G
Led B
Led R

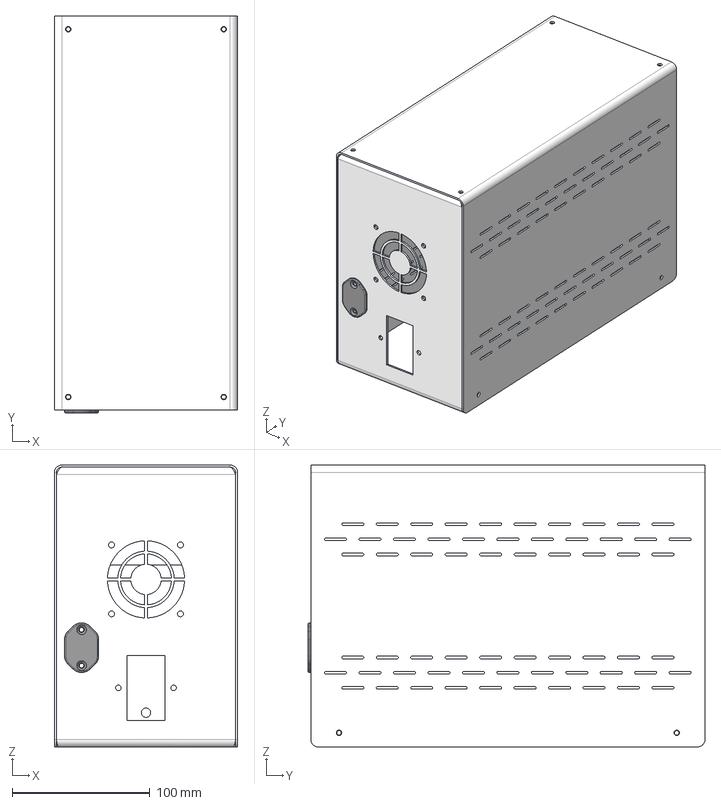
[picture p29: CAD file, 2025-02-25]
smolaan21/mechanika/sheetmetal case.step
133.0 x 288.0 x 204.5 mm

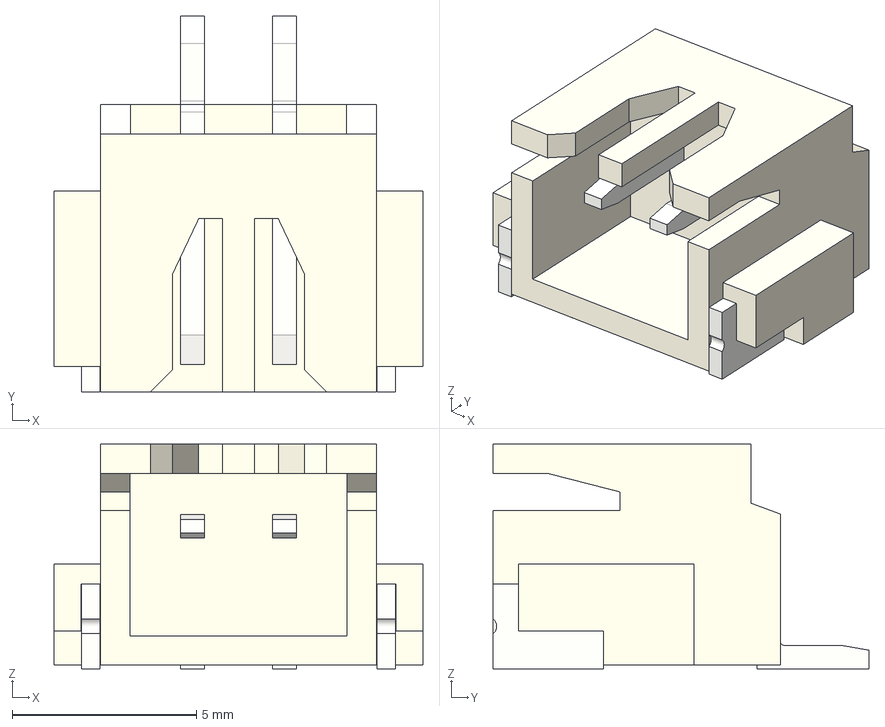
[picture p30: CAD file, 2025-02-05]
knihovna_kicad/Smola_dmp/JST-XH2-SMD.step
10.0 x 10.2 x 6.10 mm

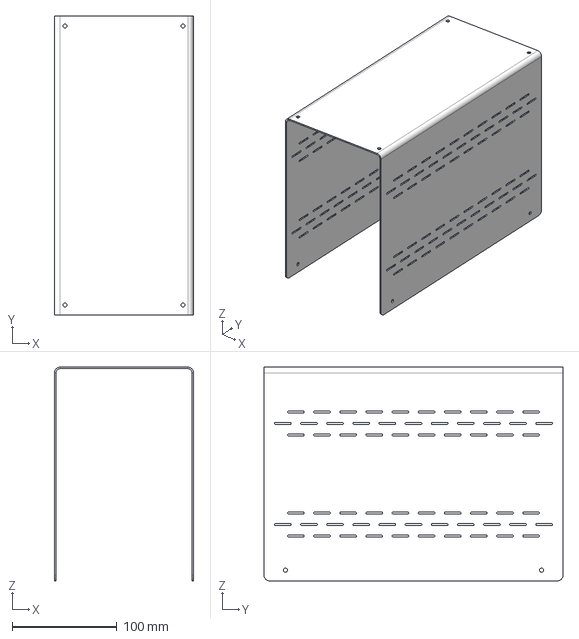
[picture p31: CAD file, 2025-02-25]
smolaan21/mechanika/sheetmetal 1.5mm - top.step
133.0 x 286.0 x 204.5 mm

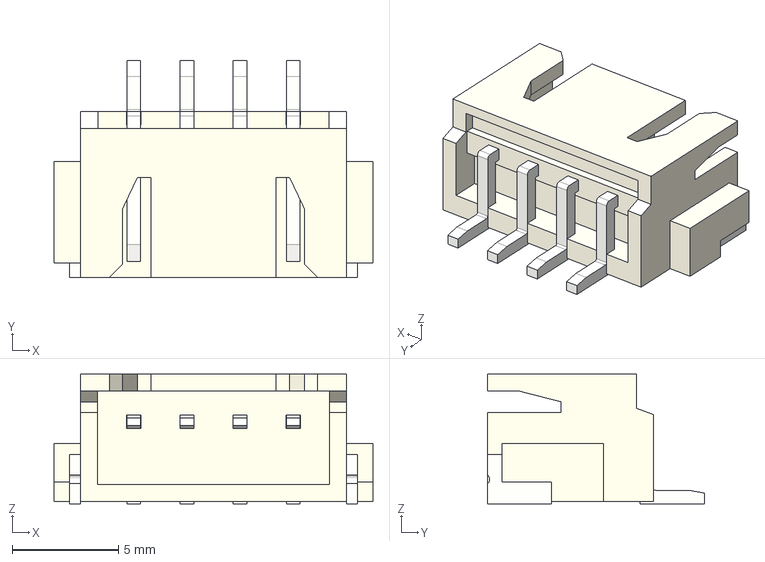
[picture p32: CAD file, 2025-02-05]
knihovna_kicad/Smola_dmp/JST-XH4-SMD.step
15.0 x 10.2 x 6.10 mm

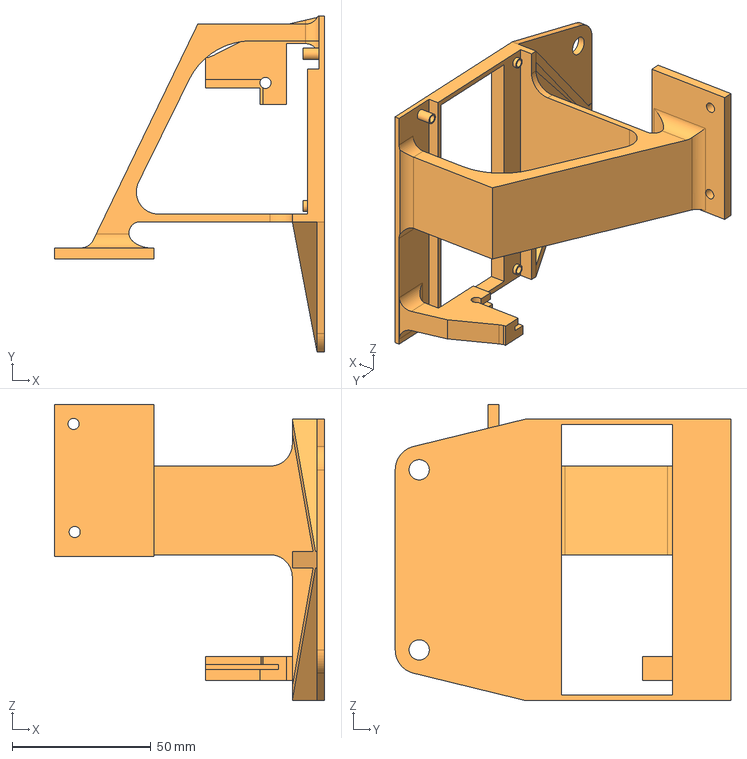
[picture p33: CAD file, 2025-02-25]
smolaan21/mechanika/board dmp - front bracket w pcb support.step
97.6 x 121.1 x 106.8 mm

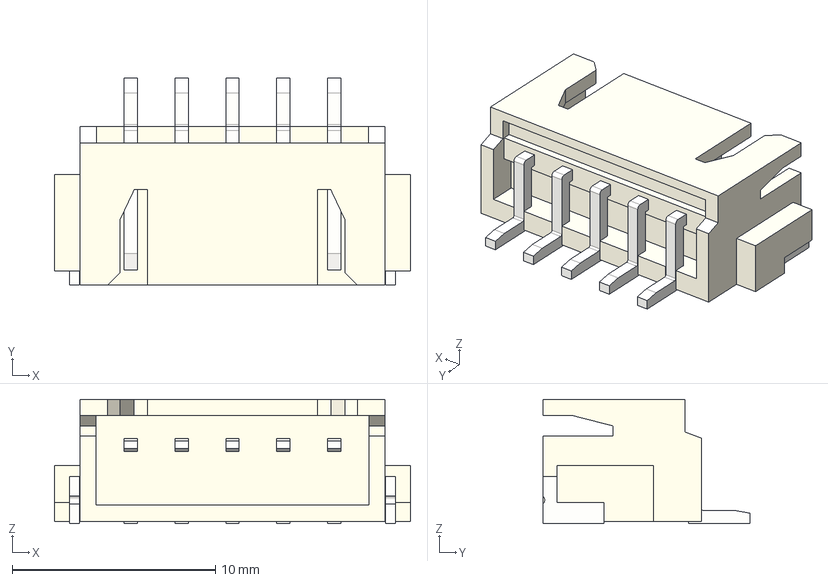
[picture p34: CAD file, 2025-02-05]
knihovna_kicad/Smola_dmp/JST-XH5-SMD.step
17.5 x 10.2 x 6.10 mm

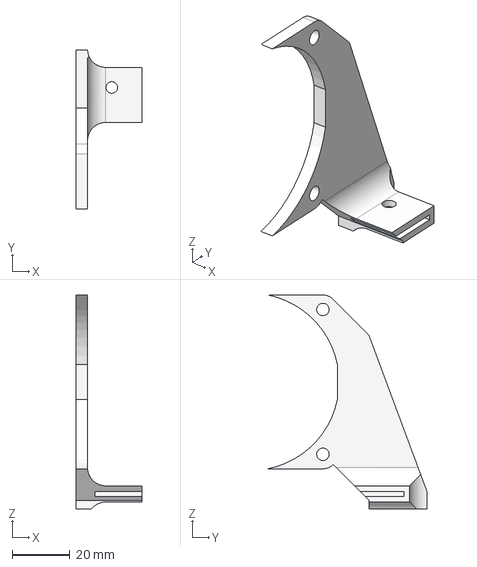
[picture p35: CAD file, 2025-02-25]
smolaan21/mechanika/board dmp - pcb suport fan.step
22.8 x 54.9 x 73.9 mm

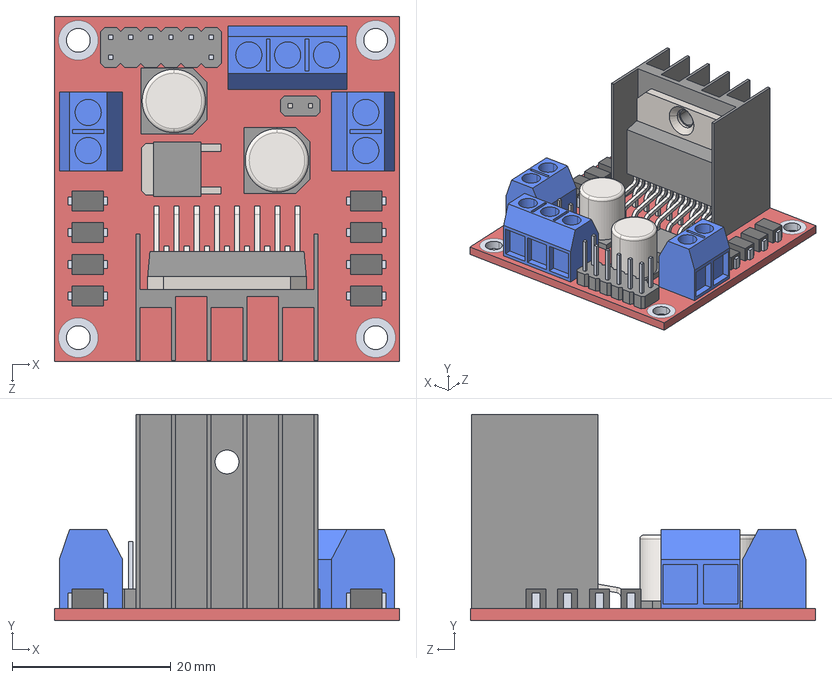
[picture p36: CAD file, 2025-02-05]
knihovna_kicad/Smola_dmp/L298N Motor Driver.STEP
43.5 x 26.0 x 43.5 mm

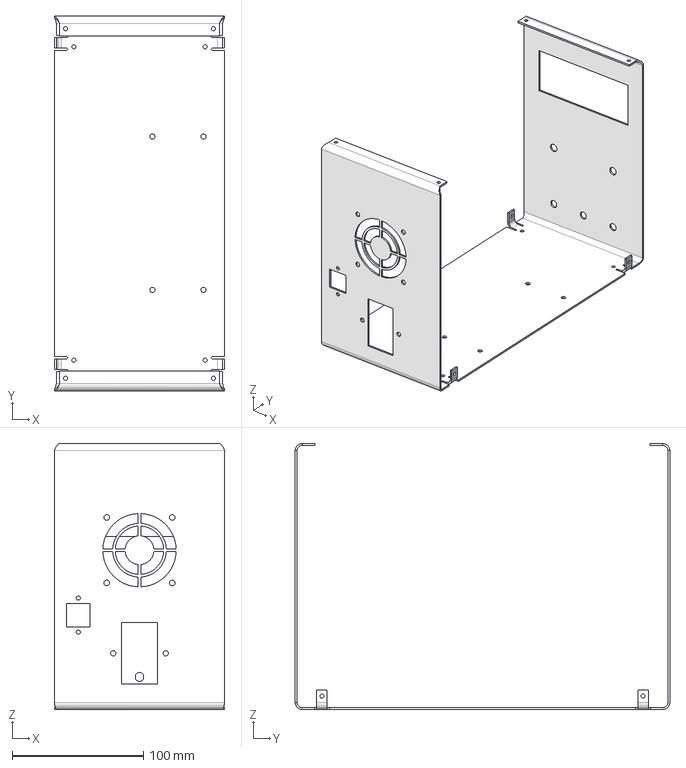
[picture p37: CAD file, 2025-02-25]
smolaan21/mechanika/sheetmetal 1.5mm - bottom.step
130.0 x 286.0 x 203.0 mm

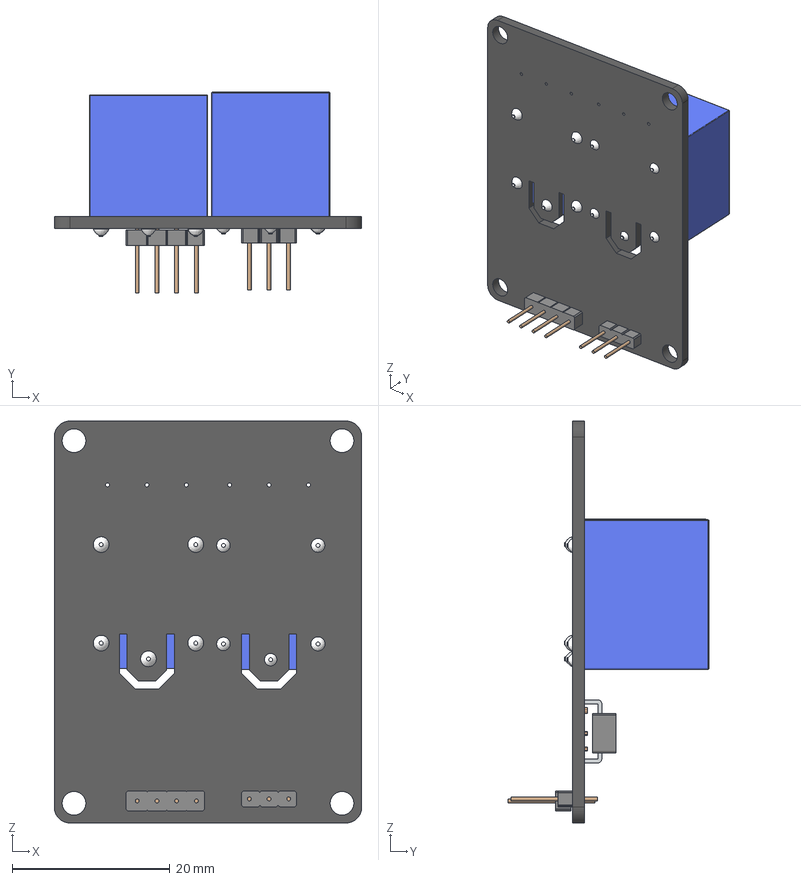
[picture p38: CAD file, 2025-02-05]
knihovna_kicad/Smola_dmp/2x_relay.step
39.0 x 25.5 x 51.0 mm

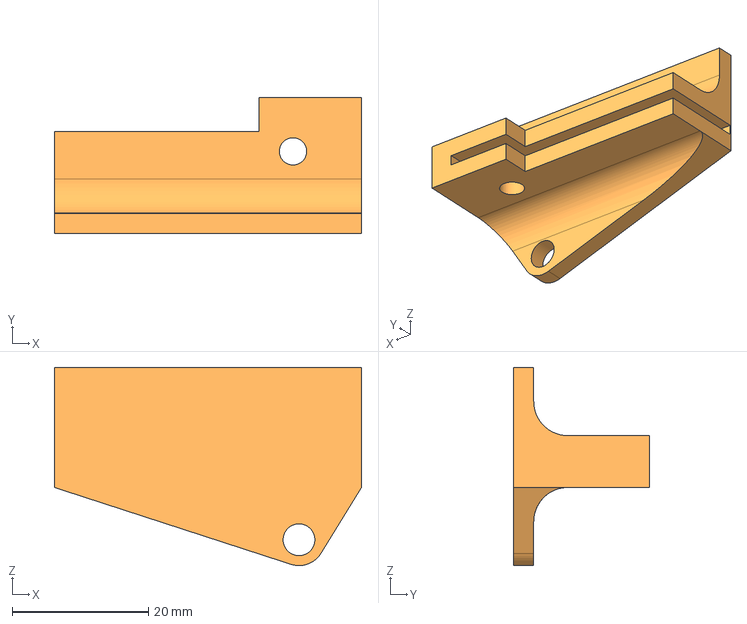
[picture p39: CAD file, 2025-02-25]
smolaan21/mechanika/board dmp - pcb suport lover L.step
45.0 x 20.0 x 29.0 mm

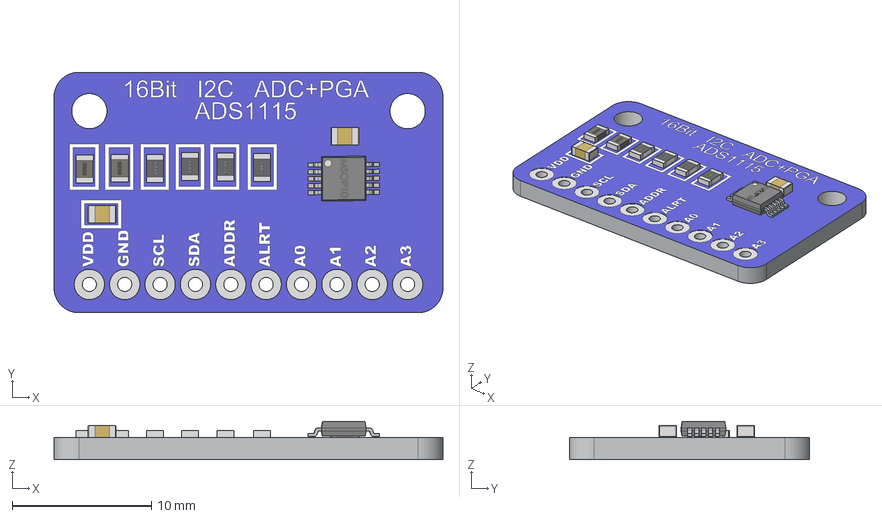
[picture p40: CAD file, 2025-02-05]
knihovna_kicad/Smola_dmp/16Bit I2C ADC+PGA - ADS1115.stp
27.9 x 17.3 x 2.74 mm
ADS1115
0805 Capacitor x 2
0805 Inductor x 2
0805 Resistor x 4
MSOP10

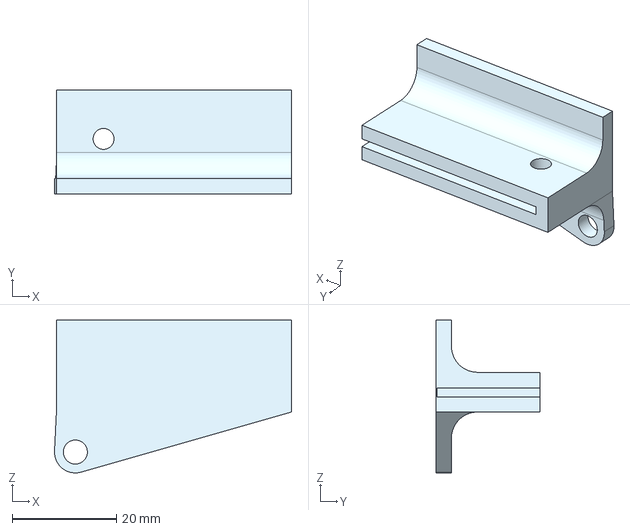
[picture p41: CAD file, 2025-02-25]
smolaan21/mechanika/board dmp - pcb suport lover P.step
45.4 x 20.0 x 29.3 mm

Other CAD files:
knihovna_kicad/Smola_dmp/100W 30OHM RESISTOR.STEP
smolaan21/mechanika/sheetmetal 1.5mm - programing port cap.step
smolaan21/mechanika/stencil_front.step

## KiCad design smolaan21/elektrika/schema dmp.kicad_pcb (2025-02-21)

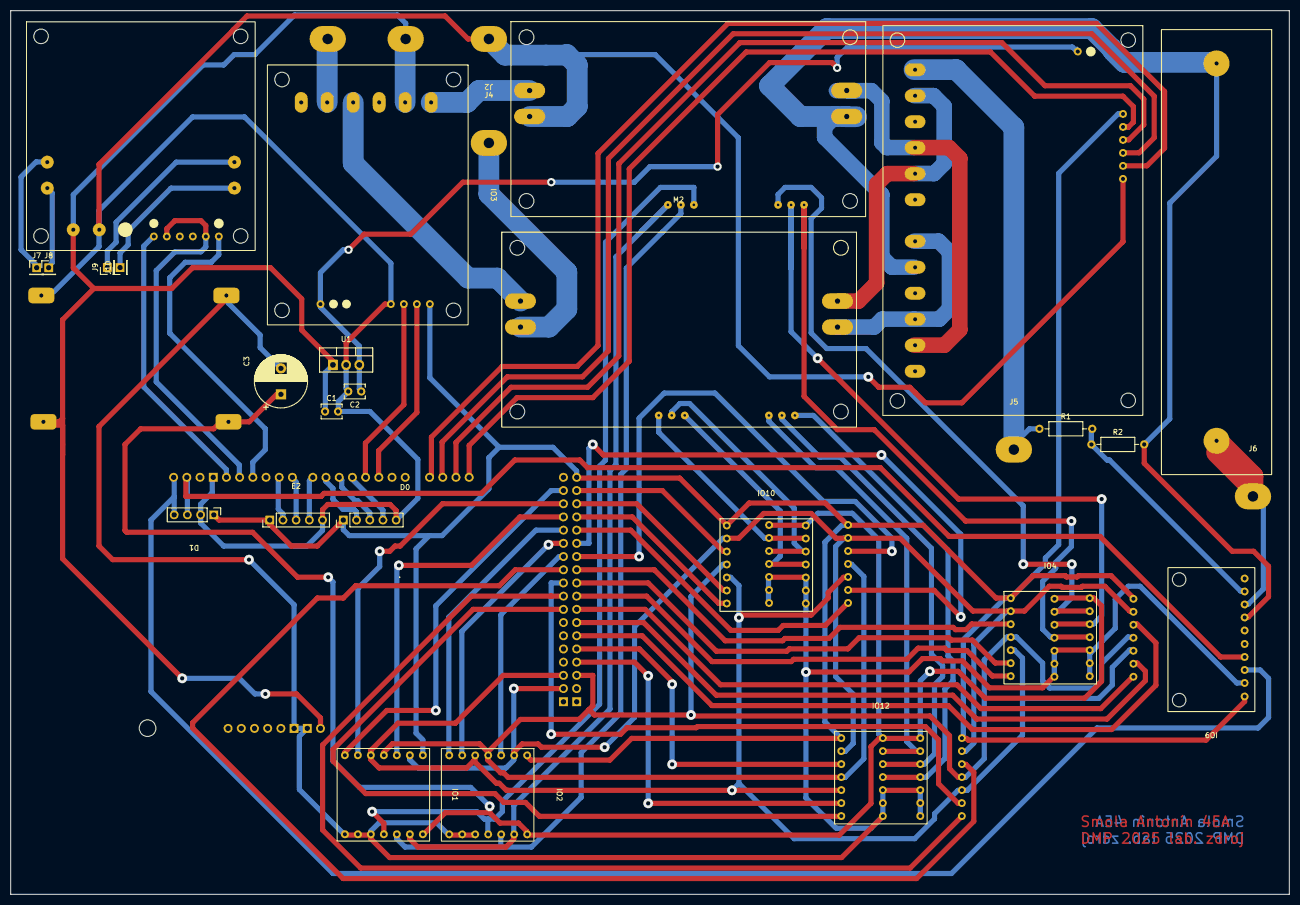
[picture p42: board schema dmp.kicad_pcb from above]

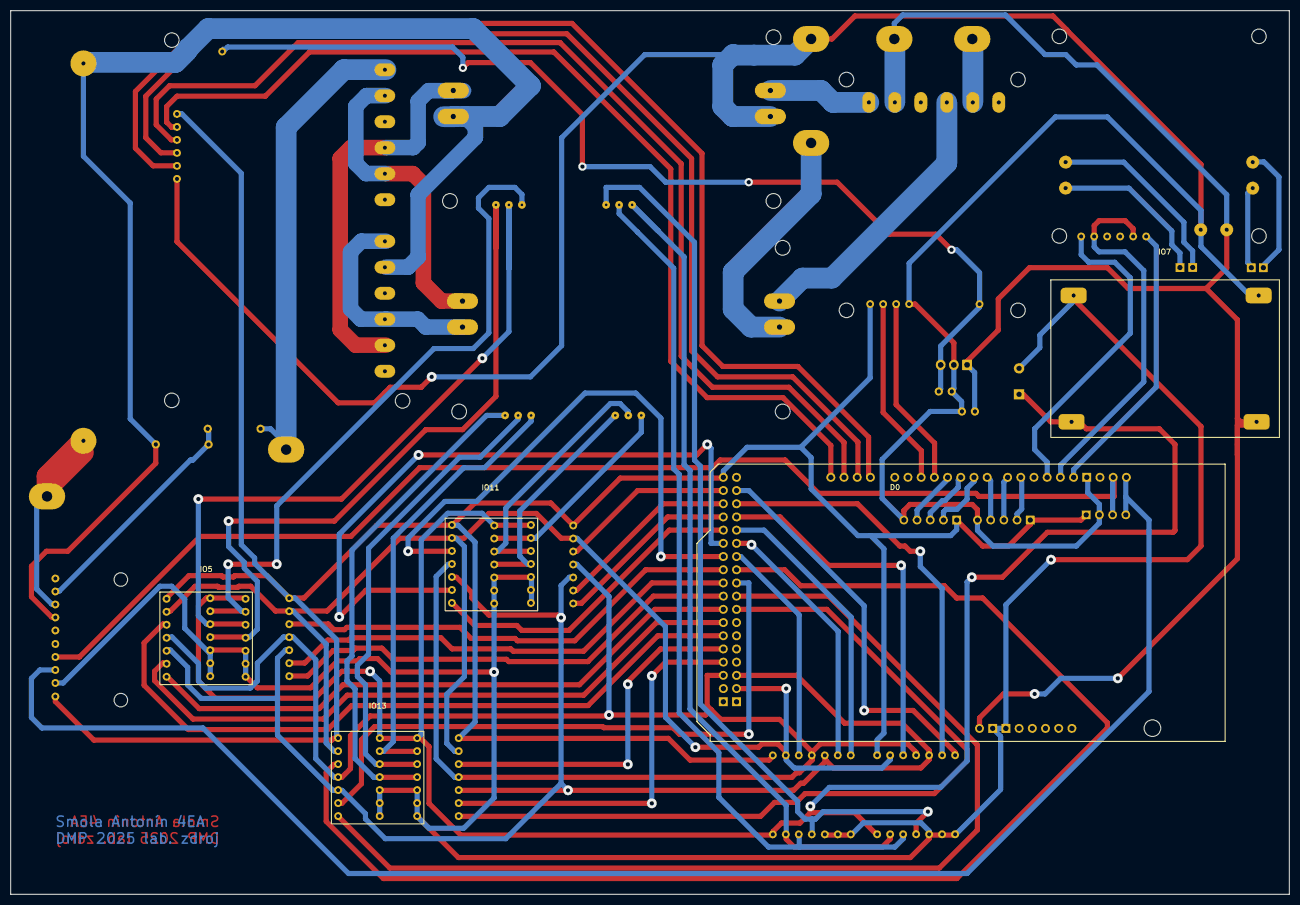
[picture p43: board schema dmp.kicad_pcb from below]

Board: 2 copper layers, 246.0 x 170.0 mm, 36 parts (4 on the bottom side), 77 nets.

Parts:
A1: Arduino_Mega2560_R3_Shield; arduino_mega
C1: 0,1 µF; C_Disc_D3.8mm_W2.6mm_P2.50mm
C2: 0,01 µF; C_Disc_D3.8mm_W2.6mm_P2.50mm
C3: 680uF/50V; CP_Radial_D10.0mm_P5.00mm
D1: display
E1: enkoder U; enkoder
E2: enkoder I; enkoder
IO1, IO2, IO10, IO11: MCP41HV51-502E; MCP41HV51
IO3: rele_2x
IO4, IO5, IO12, IO13: MCP41HV51-104E; MCP41HV51
IO7: step_up; step_up_module
IO8: rele_4x
IO9: ADS1115_I2C; ADS1115
IO14: H_mustek
J1: +12v; conn
J2: GND; conn
J3: +12v 2; conn
J4: GND2; conn
J5: out+ regulated; conn
J6: out-; conn
J7: FAN1+; PinHeader_1x01_P2.54mm_Vertical
J8: FAN1-; PinHeader_1x01_P2.54mm_Vertical
J9: FAN2+; PinHeader_1x01_P2.54mm_Vertical
J10: FAN2-; PinHeader_1x01_P2.54mm_Vertical
M1, M2: CC_&_CV_modul
R1: 220k; R_Axial_DIN0207_L6.3mm_D2.5mm_P10.16mm_Horizontal
R2: 17k8; R_Axial_DIN0207_L6.3mm_D2.5mm_P10.16mm_Horizontal
R3: 0.2R; power_rezistor_100w_0.2R
U1: L78S05CV; TO-220-3_Vertical

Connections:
12V+: A1.VIN, C1.1, IO3.22, IO7.1 (VC_+12V), IO14.5 (+12v), J1.1, U1.1 (IN)
+30V digipot: C3.1, IO1.14 (V+30v), IO2.14 (V+30v), IO4.14 (V+30v), IO5.14 (V+30v), IO7.3 (U_OUT), IO10.14 (V+30v), IO11.14 (V+30v), IO12.14 (V+30v), IO13.14 (V+30v)
Arduino_EnA: A1.D13, IO14.7 (ENA)
Arduino_EnB: A1.D11, IO14.8 (ENB)
Arduino_IN2_IN4: A1.D12, IO14.9 (IN1), IO14.12 (IN4)
Arduino_SCL: A1.SCL, D1.4 (SCL), IO9.3 (SCL)
Arduino_SDA: A1.SDA, D1.3 (SDA), IO9.4 (SDA)
Arduino_rele_2x_1: A1.D3 (D3_INT1), IO3.14 (IN1)
Arduino_rele_2x_2: A1.D2 (D2_INT0), IO3.24 (IN2)
Arduino_rele_4x_1: A1.D14 (D14/TX3), IO8.14 (IN1)
Arduino_rele_4x_2: A1.D15 (D15/RX3), IO8.24 (IN2)
Arduino_rele_4x_3: A1.D16 (D16/TX2), IO8.34 (IN3)
Arduino_rele_4x_4: A1.D17 (D17/RX2), IO8.44 (IN4)
CC1: IO10.13 (P0A), IO11.13 (P0A), M2.5 (TRIMR_CC_1)
CC2: IO10.12 (P0W), IO11.12 (P0W), M2.6 (TRIMR_CC_2)
CC3: IO10.11 (P0B), IO11.11 (P0B), M2.7 (TRIMR_CC_3)
CV1: IO12.13 (P0A), IO13.13 (P0A), M2.8 (TRIMR_CV_1)
CV2: IO12.12 (P0W), IO13.12 (P0W), M2.9 (TRIMR_CV_2)
CV3: IO12.11 (P0B), IO13.11 (P0B), M2.10 (TRIMR_CV_3)
GNDD: A1.GND1 (GND), C1.2, C2.2, D1.2 (VCC), E1.5 (GND), E2.5 (GND), IO3.1 (GND), IO7.2 (GND_IN), IO8.1 (GND), IO14.6 (GND), J2.1, M1.2 (IN_GNDD), U1.2 (GND)
JD-VCC: C2.1, IO3.3 (JD-VCC), IO8.3 (JD-VCC), U1.3 (OUT)
MISO_SDO: A1.D50 (D50_MISO), IO1.5 (SDO), IO2.5 (SDO), IO4.5 (SDO), IO5.5 (SDO), IO10.5 (SDO), IO11.5 (SDO), IO12.5 (SDO), IO13.5 (SDO)
MOSI_SDI: A1.D51 (D51_MOSI), IO1.4 (SDI), IO2.4 (SDI), IO4.4 (SDI), IO5.4 (SDI), IO10.4 (SDI), IO11.4 (SDI), IO12.4 (SDI), IO13.4 (SDI)
unnamed: IO1.13 (P0A), IO2.13 (P0A), M1.5 (TRIMR_CC_1)
unnamed: IO1.11 (P0B), IO2.11 (P0B), M1.7 (TRIMR_CC_3)
unnamed: IO1.12 (P0W), IO2.12 (P0W), M1.6 (TRIMR_CC_2)
unnamed: IO4.13 (P0A), IO5.13 (P0A), M1.8 (TRIMR_CV_1)
unnamed: IO4.11 (P0B), IO5.11 (P0B), M1.10 (TRIMR_CV_3)
unnamed: IO4.12 (P0W), IO5.12 (P0W), M1.9 (TRIMR_CV_2)
unnamed: IO8.22, IO9.7 (A0), M1.4 (OUT_GNDD), R2.2, R3.1
unnamed: IO9.8 (A1), J6.1, R3.2
unnamed: IO9.9 (A2), R1.2, R2.1
unnamed: IO14.1 (OUT1), J7.1
unnamed: IO14.2 (OUT2), J8.1
unnamed: IO14.3 (OUT3), J10.1
unnamed: IO14.4 (OUT4), J9.1
unnamed: IO3.12, J3.1
unnamed: J4.1, M2.2 (IN_GNDD)
unnamed: IO8.43, J5.1, R1.1
unnamed: IO3.23, M1.1 (IN_DC_0-30V)
unnamed: IO8.12, IO8.33, M1.3 (OUT_DC_0-30V)
unnamed: IO3.13, M2.1 (IN_DC_0-30V)
unnamed: IO8.32, IO8.42, M2.3 (OUT_DC_0-30V)
unnamed: IO8.13, IO8.23, M2.4 (OUT_GNDD)
arduino 5v: A1.5V4 (5V), D1.1 (GND), E1.1 (5V), E2.1 (5V), IO1.1 (VL_+5v), IO2.1 (VL_+5v), IO3.2 (VCC), IO4.1 (VL_+5v), IO5.1 (VL_+5v), IO8.2 (VCC), IO9.1 (VDD), IO10.1 (VL_+5v), IO11.1 (VL_+5v), IO12.1 (VL_+5v), IO13.1 (VL_+5v)
arduino GND3: A1.GND2 (GND), A1.GND3 (GND), C3.2, IO1.8 (NC), IO1.9 (DGND), IO1.10 (V-), IO2.8 (NC), IO2.9 (DGND), IO2.10 (V-), IO4.8 (NC), IO4.9 (DGND), IO4.10 (V-), IO5.8 (NC), IO5.9 (DGND), IO5.10 (V-), IO7.4 (GND_OUT), IO9.2 (GND), IO10.8 (NC), IO10.9 (DGND), IO10.10 (V-), IO11.8 (NC), IO11.9 (DGND), IO11.10 (V-), IO12.8 (NC), IO12.9 (DGND), IO12.10 (V-), IO13.8 (NC), IO13.9 (DGND), IO13.10 (V-)
arduino sck: A1.D52 (D52_SCK), IO1.2 (SCK), IO2.2 (SCK), IO4.2 (SCK), IO5.2 (SCK), IO10.2 (SCK), IO11.2 (SCK), IO12.2 (SCK), IO13.2 (SCK)
arduino_CS_1: A1.D26, IO1.3 (CS)
arduino_CS_2: A1.D32, IO2.3 (CS)
arduino_CS_3: A1.D35, IO4.3 (CS)
arduino_CS_4: A1.D45, IO5.3 (CS)
arduino_CS_5: A1.D23, IO10.3 (CS)
arduino_CS_6: A1.D33, IO11.3 (CS)
arduino_CS_7: A1.D47, IO12.3 (CS)
arduino_CS_8: A1.D34, IO13.3 (CS)
arduino_SHDN_1: A1.D22, IO1.7 (SHDN)
arduino_SHDN_2: A1.D28, IO2.7 (SHDN)
arduino_SHDN_3: A1.D39, IO4.7 (SHDN)
arduino_SHDN_4: A1.D41, IO5.7 (SHDN)
arduino_SHDN_5: A1.D27, IO10.7 (SHDN)
arduino_SHDN_6: A1.D29, IO11.7 (SHDN)
arduino_SHDN_7: A1.D40, IO12.7 (SHDN)
arduino_SHDN_8: A1.D38, IO13.7 (SHDN)
arduino_WLAT_1: A1.D24, IO1.6 (WLAT)
arduino_WLAT_2: A1.D30, IO2.6 (WLAT)
arduino_WLAT_3: A1.D37, IO4.6 (WLAT)
arduino_WLAT_4: A1.D43, IO5.6 (WLAT)
arduino_WLAT_5: A1.D25, IO10.6 (WLAT)
arduino_WLAT_6: A1.D31, IO11.6 (WLAT)
arduino_WLAT_7: A1.D49, IO12.6 (WLAT)
arduino_WLAT_8: A1.D36, IO13.6 (WLAT)
enkoder I KEY: A1.D9, E2.2 (KEY)
enkoder I S1: A1.D7, E2.4 (S1)
enkoder I S2: A1.D8, E2.3 (S2)
enkoder U KEY: A1.D6, E1.2 (KEY)
enkoder U S1: A1.D4, E1.4 (S1)
enkoder U S2: A1.D5, E1.3 (S2)

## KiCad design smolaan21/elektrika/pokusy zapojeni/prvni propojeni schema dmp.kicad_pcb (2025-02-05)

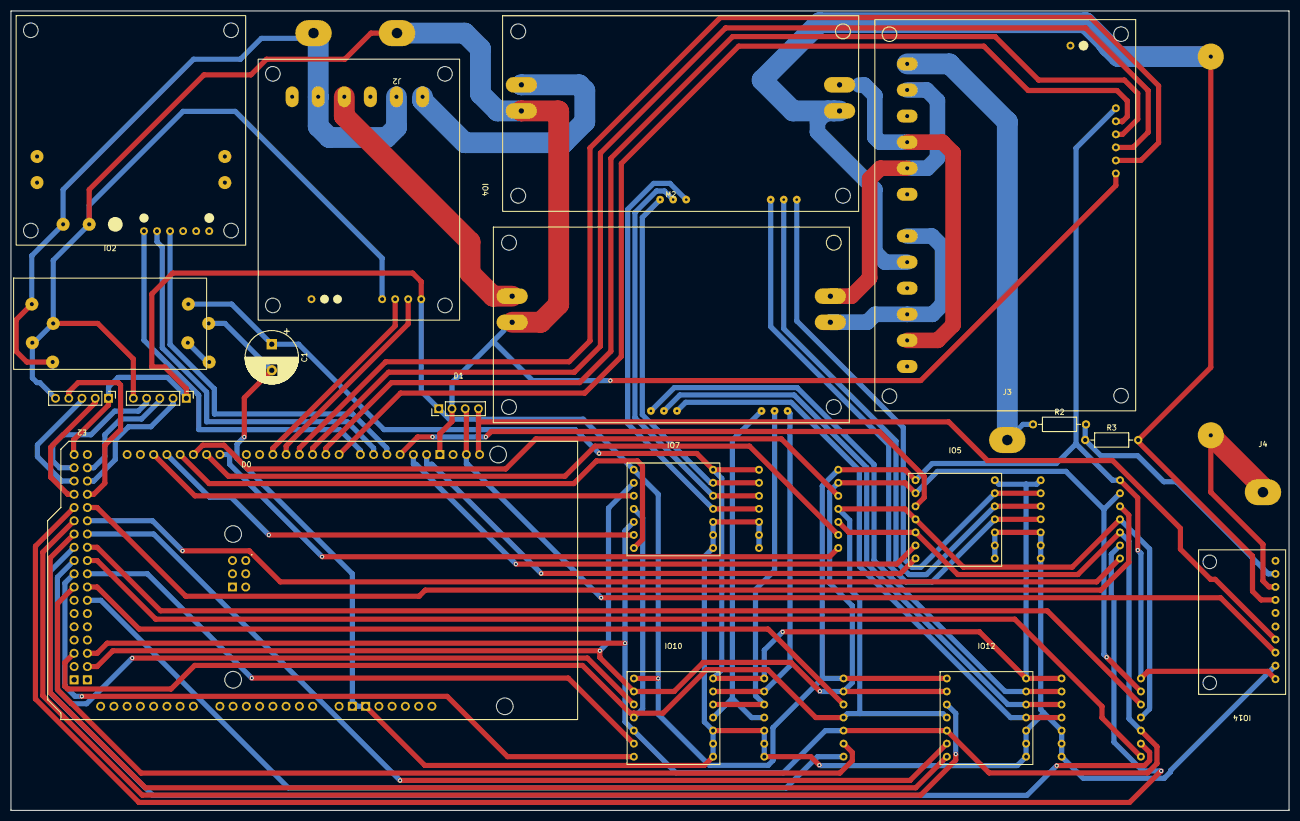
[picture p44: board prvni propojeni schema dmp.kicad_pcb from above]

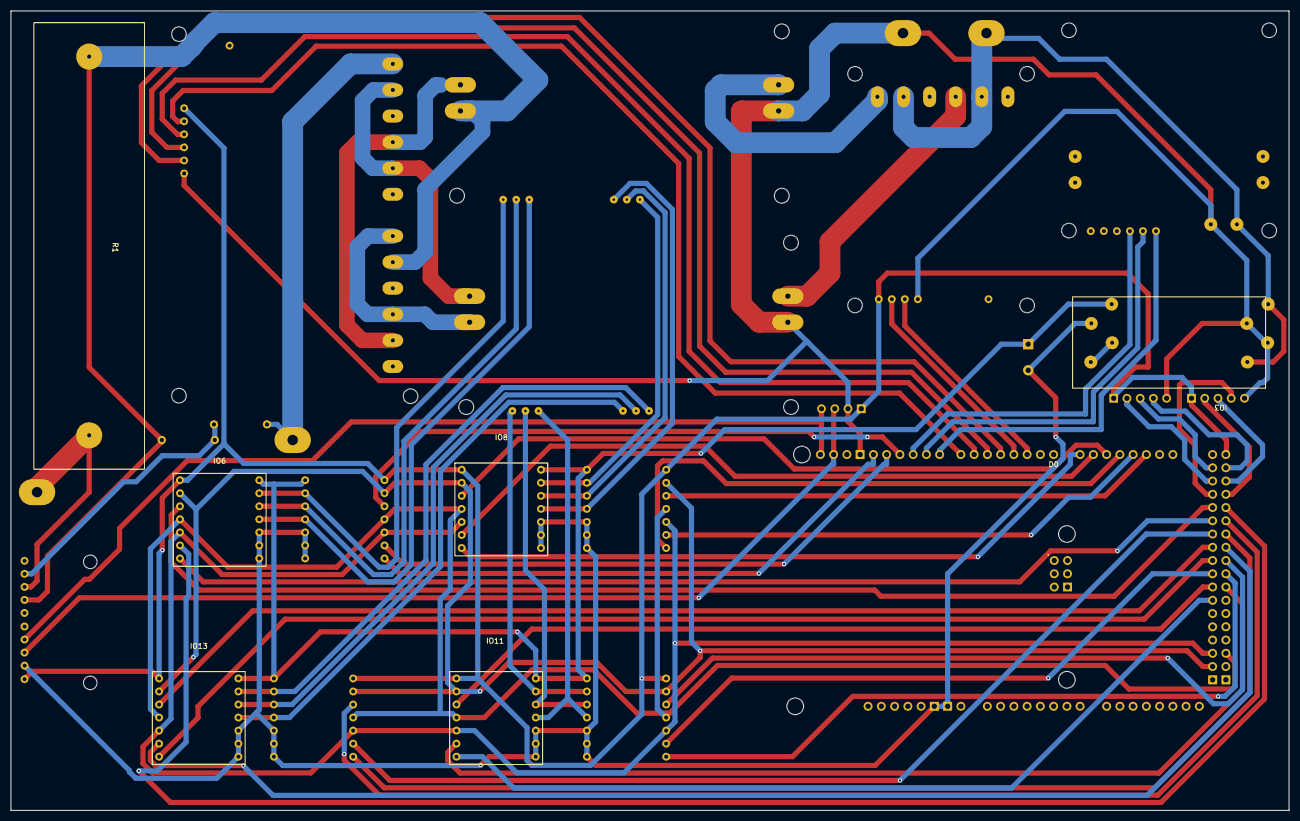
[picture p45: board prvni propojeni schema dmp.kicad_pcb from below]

Board: 2 copper layers, 245.0 x 153.2 mm, 28 parts (7 on the bottom side), 71 nets.

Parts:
A1: Arduino_Mega2560_R3_Shield; arduino_mega
C1: 680uF/50V; CP_Radial_D10.0mm_P5.00mm
D1: display
E1: enkoder U; enkoder
E2: enkoder I; enkoder
IO1: H_mustek
IO2, IO3: step_up_28V
IO4: rele_2x
IO5, IO6, IO10, IO11: MCP41HV51-104E; MCP41HV51
IO7, IO8, IO12, IO13: MCP41HV51-502E; MCP41HV51
IO9: rele_4x
IO14: ADS1115_I2C; ADS1115
J1: +12v; conn
J2: GND; conn
J3: out+ regulated; conn
J4: out-; conn
M1, M2: CC_&_CV_modul
R1: 0.2R; power_rezistor_100w_0.2R
R2: 220k; R_Axial_DIN0207_L6.3mm_D2.5mm_P10.16mm_Horizontal
R3: 17k8; R_Axial_DIN0207_L6.3mm_D2.5mm_P10.16mm_Horizontal

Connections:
12V+: IO1.5 (+12v), IO2.1 (VC_+12V), IO3.1 (VC_+12V), IO4.12, IO4.22, J1.1
+30V digipot: C1.1, IO2.3 (28V_OUT), IO5.14 (V+30v), IO6.14 (V+30v), IO7.14 (V+30v), IO8.14 (V+30v), IO10.14 (V+30v), IO11.14 (V+30v), IO12.14 (V+30v), IO13.14 (V+30v)
Arduino_EnA: A1.D8, IO1.7 (ENA)
Arduino_IN1: A1.D9, IO1.9 (IN1)
Arduino_IN2: A1.D10, IO1.10 (IN2)
Arduino_SCL: A1.SCL, D1.4 (SCL), IO14.4 (SDA)
Arduino_SDA: A1.SDA, D1.3 (SDA), IO14.3 (SCL)
Arduino_rele_2x_1: A1.D2 (D2_INT0), IO4.14 (IN1)
Arduino_rele_2x_2: A1.D3 (D3_INT1), IO4.24 (IN2)
Arduino_rele_4x_1: A1.D4, IO9.14 (IN1)
Arduino_rele_4x_2: A1.D5, IO9.24 (IN2)
Arduino_rele_4x_3: A1.D6, IO9.34 (IN3)
Arduino_rele_4x_4: A1.D7, IO9.44 (IN4)
GNDD: A1.GND1 (GND), D1.2 (VCC), E1.5 (GND), E2.5 (GND), IO1.6 (GND), IO2.2 (GND_IN), IO3.2 (GND_IN), IO4.1 (GND), IO9.1 (GND), J2.1, M1.2 (IN_GNDD), M2.2 (IN_GNDD)
MISO_SDO: A1.D50 (D50_MISO), IO5.5 (SDO), IO6.5 (SDO), IO7.5 (SDO), IO8.5 (SDO), IO10.5 (SDO), IO11.5 (SDO), IO12.5 (SDO), IO13.5 (SDO)
MOSI_SDI: A1.D51 (D51_MOSI), IO5.4 (SDI), IO6.4 (SDI), IO7.4 (SDI), IO8.4 (SDI), IO10.4 (SDI), IO11.4 (SDI), IO12.4 (SDI), IO13.4 (SDI)
unnamed: A1.D24, E1.2 (KEY)
unnamed: A1.D23, E1.4 (S1)
unnamed: A1.D22, E1.3 (S2)
unnamed: A1.D27, E2.2 (KEY)
unnamed: A1.D26, E2.4 (S1)
unnamed: A1.D25, E2.3 (S2)
unnamed: IO2.4 (GND_OUT), IO3.3 (28V_OUT)
unnamed: IO5.13 (P0A), IO6.13 (P0A), M1.10 (TRIMR_CV_3)
unnamed: IO5.11 (P0B), IO6.11 (P0B), M1.8 (TRIMR_CV_1)
unnamed: IO5.12 (P0W), IO6.12 (P0W), M1.9 (TRIMR_CV_2)
unnamed: IO7.13 (P0A), IO8.13 (P0A), M1.5 (TRIMR_CC_1)
unnamed: IO7.11 (P0B), IO8.11 (P0B), M1.7 (TRIMR_CC_3)
unnamed: IO7.12 (P0W), IO8.12 (P0W), M1.6 (TRIMR_CC_2)
unnamed: IO10.13 (P0A), IO11.13 (P0A), M2.10 (TRIMR_CV_3)
unnamed: IO10.11 (P0B), IO11.11 (P0B), M2.8 (TRIMR_CV_1)
unnamed: IO10.12 (P0W), IO11.12 (P0W), M2.9 (TRIMR_CV_2)
unnamed: IO12.13 (P0A), IO13.13 (P0A), M2.5 (TRIMR_CC_1)
unnamed: IO12.11 (P0B), IO13.11 (P0B), M2.7 (TRIMR_CC_3)
unnamed: IO12.12 (P0W), IO13.12 (P0W), M2.6 (TRIMR_CC_2)
unnamed: IO9.22, IO14.7 (A0), M1.4 (OUT_GNDD), R1.1, R3.2
unnamed: IO14.8 (A1), J4.1, R1.2
unnamed: IO14.9 (A2), R2.2, R3.1
unnamed: IO9.43, J3.1, R2.1
unnamed: IO4.23, M1.1 (IN_DC_0-30V)
unnamed: IO9.12, IO9.33, M1.3 (OUT_DC_0-30V)
unnamed: IO4.13, M2.1 (IN_DC_0-30V)
unnamed: IO9.32, IO9.42, M2.3 (OUT_DC_0-30V)
unnamed: IO9.13, IO9.23, M2.4 (OUT_GNDD)
arduino 5v: A1.5V4 (5V), D1.1 (GND), E1.1 (5V), E2.1 (5V), IO4.2 (VCC), IO5.1 (VL_+5v), IO6.1 (VL_+5v), IO7.1 (VL_+5v), IO8.1 (VL_+5v), IO9.2 (VCC), IO10.1 (VL_+5v), IO11.1 (VL_+5v), IO12.1 (VL_+5v), IO13.1 (VL_+5v), IO14.1 (VDD)
arduino GND3: A1.GND2 (GND), A1.GND3 (GND), C1.2, IO3.4 (GND_OUT), IO5.8 (NC), IO5.9 (DGND), IO5.10 (V-), IO6.8 (NC), IO6.9 (DGND), IO6.10 (V-), IO7.8 (NC), IO7.9 (DGND), IO7.10 (V-), IO8.8 (NC), IO8.9 (DGND), IO8.10 (V-), IO10.8 (NC), IO10.9 (DGND), IO10.10 (V-), IO11.8 (NC), IO11.9 (DGND), IO11.10 (V-), IO12.8 (NC), IO12.9 (DGND), IO12.10 (V-), IO13.8 (NC), IO13.9 (DGND), IO13.10 (V-), IO14.2 (GND)
arduino sck: A1.D52 (D52_SCK), IO5.2 (SCK), IO6.2 (SCK), IO7.2 (SCK), IO8.2 (SCK), IO10.2 (SCK), IO11.2 (SCK), IO12.2 (SCK), IO13.2 (SCK)
arduino_CS_1: A1.D19 (D19/RX1), IO7.3 (CS)
arduino_CS_2: A1.D16 (D16/TX2), IO8.3 (CS)
arduino_CS_3: A1.D11, IO5.3 (CS)
arduino_CS_4: A1.D28, IO6.3 (CS)
arduino_CS_5: A1.D31, IO12.3 (CS)
arduino_CS_6: A1.D34, IO13.3 (CS)
arduino_CS_7: A1.D37, IO10.3 (CS)
arduino_CS_8: A1.D40, IO11.3 (CS)
arduino_SHDN_1: A1.D17 (D17/RX2), IO7.7 (SHDN)
arduino_SHDN_2: A1.D14 (D14/TX3), IO8.7 (SHDN)
arduino_SHDN_3: A1.D13, IO5.7 (SHDN)
arduino_SHDN_4: A1.D30, IO6.7 (SHDN)
arduino_SHDN_5: A1.D33, IO12.7 (SHDN)
arduino_SHDN_6: A1.D36, IO13.7 (SHDN)
arduino_SHDN_7: A1.D39, IO10.7 (SHDN)
arduino_SHDN_8: A1.D42, IO11.7 (SHDN)
arduino_WLAT_1: A1.D18 (D18/TX1), IO7.6 (WLAT)
arduino_WLAT_2: A1.D15 (D15/RX3), IO8.6 (WLAT)
arduino_WLAT_3: A1.D12, IO5.6 (WLAT)
arduino_WLAT_4: A1.D29, IO6.6 (WLAT)
arduino_WLAT_5: A1.D32, IO12.6 (WLAT)
arduino_WLAT_6: A1.D35, IO13.6 (WLAT)
arduino_WLAT_7: A1.D38, IO10.6 (WLAT)
arduino_WLAT_8: A1.D41, IO11.6 (WLAT)

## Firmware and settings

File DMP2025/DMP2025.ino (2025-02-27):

#include "MCP41HVX1.h"
#include "SPI.h"
#include <EEPROM.h>
#include <Wire.h> // drát
#include <LiquidCrystal_I2C.h> 
#include <ADS1X15.h> // AD converter 
#define ON 1
#define OFF 0
int prvnispusteni = 1;


#define programversion 1.00
#define rate_of_refreshing 350 // refreshrate hlavni obrazovky
#define DEBUG ON //    ON / OFF    1/0     debugovaci odesilani hodnot do seriove linky

////////////////////////////////////// relay piny
//PIN_relay5 = napajni modulu 2 (dole)
//PIN_relay6 = napajni modulu 1 (nahore)
//PIN_relay4 = hlavní OUT vypinac

//PIN_relay2 + PIN_relay3 = paraler
//PIN_relay1 = ser  
#define PIN_relay5 3 //napajni modulu 2
#define PIN_relay6 2 //napajni modulu 1


#define PIN_relay1 14
#define PIN_relay2 15
#define PIN_relay3 16
#define PIN_relay4 17

int modulepower1 = 0;
int modulepower2 = 0;
int serparrelaymode = 0; // 0 off    1 serial    2 paraler
int output = 0; // 0 off     1 out on

////////////////////////////////////// H mustek fan control
#define fan2en 11 // inside
#define fan1en 13 // exhaust
#define fanEn 12
////////////////////////////////////// piny digitálních potenciometrů
#define FORWARD true
#define REVERSE false
#define MAX_WIPER_VALUE 255  //maximum wiper value

#define CS_PIN_1    26 //CC 1   //chip select  for SPI communications
#define WLAT_PIN_1  24          // Latch pin
#define SHDN_PIN_1  22          // resistor network enable

#define CS_PIN_2    32 //CC 1 
#define WLAT_PIN_2  30
#define SHDN_PIN_2  28

#define CS_PIN_3    35 //CV 1
#define WLAT_PIN_3  37
#define SHDN_PIN_3  39

#define CS_PIN_4    45 //CV 1
#define WLAT_PIN_4  43
#define SHDN_PIN_4  41

#define CS_PIN_5    23 //CC 2
#define WLAT_PIN_5  25
#define SHDN_PIN_5  27

#define CS_PIN_6    33 //CC 2
#define WLAT_PIN_6  31
#define SHDN_PIN_6  29
 
#define CS_PIN_7    47 //CV 2
#define WLAT_PIN_7  49
#define SHDN_PIN_7  40

#define CS_PIN_8    34 //CV 2
#define WLAT_PIN_8  36
#define SHDN_PIN_8  38


int set1 = 150; //CC 1 
int set2 = 150; //CC 1 
int set3 = 200; //CV 1
int set4 = 200; //CV 1
int set5 = 150; //CC 2
int set6 = 150; //CC 2
int set7 = 200; //CV 2
int set8 = 200; //CV 2


MCP41HVX1 Digipot1(CS_PIN_1, SHDN_PIN_1, WLAT_PIN_1);     // Create an instance of the MCP41HVX1 class for controlling the digipot
MCP41HVX1 Digipot2(CS_PIN_2, SHDN_PIN_2, WLAT_PIN_2);
MCP41HVX1 Digipot3(CS_PIN_3, SHDN_PIN_3, WLAT_PIN_3);
MCP41HVX1 Digipot4(CS_PIN_4, SHDN_PIN_4, WLAT_PIN_4);
MCP41HVX1 Digipot5(CS_PIN_5, SHDN_PIN_5, WLAT_PIN_5);
MCP41HVX1 Digipot6(CS_PIN_6, SHDN_PIN_6, WLAT_PIN_6);
MCP41HVX1 Digipot7(CS_PIN_7, SHDN_PIN_7, WLAT_PIN_7);
MCP41HVX1 Digipot8(CS_PIN_8, SHDN_PIN_8, WLAT_PIN_8);

////////////////////////////////////// enkoder 1
#define PIN_DT  7 // napětí // 7 8 9
#define PIN_CLK 8
#define PIN_BTN1 9
int lastStateDT;
int currentStateDT;
int stepCounter = 0;



unsigned long lastDebounceTime = 0; // pamet zpoždění enkoderu // enkoder napeti hlavni obrazovka
const unsigned long debounceDelay = 5; // zpoždění enkoderu

unsigned long lastDebounceTime2 = 0; // pamet zpoždění enkoderu // enkoder u zadavani napeti
const unsigned long debounceDelay2 = 5; // zpoždění enkoderu

unsigned long lastDebounceTime3 = 0; // pamet zpoždění enkoderu // tlacitko u zadavani napeti
const unsigned long debounceDelay3 = 150; // zpoždění enkoderu

////////////////////////////////////// enkoder 2
#define PIN_DT2  4 // proud
#define PIN_CLK2 5
#define PIN_BTN2 6

int lastStateDT2;
int currentStateDT2;
int stepCounter2 = 0;


#define CCCVmodedifftreshold 0.2
static float proud = 0.5;
static float napeti = 1;
//static int napeti2 = 1;

LiquidCrystal_I2C lcd(0x27, 20, 4); //display

byte sipka[8] = { // vytvoreni znaku pro vlastniho display
  B00100, 
  B01110, 
  B11111, 
  B00100, 
  B00100, 
  B00100, 
  B11100, 
  B00000  
}; 



ADS1115 ADS(0x48);
float f = ADS.toVoltage(1);  //  voltage factor


int tik = LOW;
static int refreshrate = rate_of_refreshing;


/////////////////////////////////////////// vypocty kroku

float resistanceLookup_U[256];
constexpr float MAX_VOLTAGE = 32.0;     // max U
constexpr float RESISTOR_U_VALUE = 100000.0; // Hodnota odporu jednoho potenciometru
constexpr float TARGET_U_RESISTANCE = 50000.0; // Paralelní kombinace dvou potenciometrů
constexpr float TOLERANCE_U = 0.01;         // TOLERANCE_U pro shodu napětí
float DESIRED_U = 1.00;

float resistanceLookup_I[256];
constexpr float MAX_CURRENT = 4.00;     // max I
constexpr float RESISTOR_I_VALUE = 5000; // Hodnota odporu jednoho potenciometru
constexpr float TARGET_I_RESISTANCE = 2500.0; // Paralelní kombinace dvou potenciometrů
constexpr float TOLERANCE_I = 0.01;         // TOLERANCE_I pro shodu proudu
float DESIRED_I = 1.00;



/////////////////////////////////////////// vypocty korekce

///////////////// korekce vystupniho napětí
const int tableSize = 32; // korekce vystupniho napětí
float requestedVoltages[tableSize] = {1, 2, 3, 4, 5, 6, 7, 8, 9, 10, 11, 12, 13, 14, 15, 16, 17, 18, 19, 20, 21, 22, 23, 24, 25, 26, 27, 28, 29, 30, 31, 32};
float realVoltages[tableSize] = {1.46, 2.39, 3.32, 4.2, 5.1, 6.1, 7, 8, 8.8, 9.8, 10.7, 11.6, 12.6, 13.5, 14.4, 15.3, 16.3, 17.2, 18.1, 19.09, 20, 20.9, 21.8, 22.7, 23.7, 24.6, 25.5, 26.4, 27.4, 28.3, 29.2, 30.1};


//////////// korekce mereneho proudu
const int AtableSize = 40; // korekce mereneho proudu
float zdroj[AtableSize] = {0.2, 0.588, 0.8, 0.98, 1.18, 1.37, 1.57, 1.76, 1.94, 2.14, 2.34, 2.54, 2.73, 2.92, 3.11, 3.31, 3.49, 3.68, 3.86, 4.04, 4.23, 4.43, 4.63, 4.81, 4.99, 5.16, 5.36, 5.56, 5.72, 5.91, 6.09, 6.29, 6.49, 6.69, 6.89, 7.09, 7.32, 7.55, 7.76, 7.967};
float ampermetr[AtableSize] = {0.1, 0.5, 0.9, 1.18, 1.48, 1.77, 2.06, 2.36, 2.63, 2.93, 3.24, 3.53, 3.83, 4.13, 4.4, 4.71, 5.01, 5.31, 5.59, 5.86, 6.15, 6.47, 6.79, 7.1, 7.36, 7.63, 7.95, 8.32, 8.58, 8.89, 9.21, 9.55, 9.95, 10.29, 10.65, 10.95, 11.39, 11.75, 12.21, 12.57};

//float zdroj[AtableSize] = {0.45, 0.588, 0.8, 0.98, 1.18, 1.37, 1.57, 1.76, 1.94, 2.14, 2.34, 2.54, 2.73, 2.92, 3.11, 3.31, 3.49, 3.68, 3.86, 4.04, 4.23, 4.43, 4.63, 4.81, 4.99, 5.16, 5.36, 5.56, 5.72, 5.91, 6.09, 6.29, 6.49, 6.69, 6.89, 7.09, 7.32, 7.55, 7.76, 7.967};
//float ampermetr[AtableSize] = {0.18, 0.5, 0.9, 1.18, 1.48, 1.77, 2.06, 2.36, 2.63, 2.93, 3.24, 3.53, 3.83, 4.13, 4.4, 4.71, 5.01, 5.31, 5.59, 5.86, 6.15, 6.47, 6.79, 7.1, 7.36, 7.63, 7.95, 8.32, 8.58, 8.89, 9.21, 9.55, 9.95, 10.29, 10.65, 10.95, 11.39, 11.75, 12.21, 12.57};

///////////// korekce vystupniho proudu
const int A_Out_tableSize = 41; // korekce vystupniho proudu
float setCurrent[A_Out_tableSize] = {0, 0.2, 0.4, 0.6, 0.8, 1, 1.2, 1.4, 1.6, 1.8, 2, 2.2, 2.4, 2.6, 2.8, 3, 3.2, 3.4, 3.6, 3.8, 4, 4.2, 4.4, 4.6, 4.8, 5, 5.2, 5.4, 5.6, 5.8, 6, 6.2, 6.4, 6.6, 6.8, 7, 7.2, 7.4, 7.6, 7.8, 8};
float realCurrent[A_Out_tableSize] = {0, 0.38, 0.588, 0.8, 0.98, 1.18, 1.2, 1.4, 1.6, 1.8, 2, 2.2, 2.4, 2.6, 2.8, 3, 3.2, 3.4, 3.6, 3.8, 4, 4.2, 4.4, 4.6, 4.8, 5, 5.2, 5.4, 5.6, 5.8, 6, 6.2, 6.4, 6.6, 6.8, 7, 7.2, 7.4, 7.6, 7.8, 8};



const int A_AtableSize = 40; // korekce vystupniho proudu V2
float A_ampermetr[A_AtableSize] = {0, 0.2, 0.4, 0.6, 0.8, 1.0, 1.2, 1.4, 1.6, 1.8, 2.0, 2.2, 2.4, 2.6, 2.8, 3.0, 3.2, 3.4, 3.6, 3.8, 4.0, 4.2, 4.4, 4.6, 4.8, 5.0, 5.2, 5.4, 5.6, 5.8, 6.0, 6.2, 6.4, 6.6, 6.8, 7.0, 7.2, 7.4, 7.6, 7.8};
float A_zdroj[A_AtableSize] = {0, 0.38, 0.58, 0.79, 0.98, 1.17, 1.37, 1.57, 1.76, 1.94, 2.14, 2.33, 2.53, 2.74, 2.92, 3.12, 3.31, 3.50, 3.69, 3.86, 4.05, 4.24, 4.43, 4.63, 4.81, 4.99, 5.19, 5.38, 5.56, 5.73, 5.91, 6.09, 6.26, 6.50, 6.68, 6.88, 7.08, 7.29, 7.51, 7.70};

const int C_tableSize = 15; 
float A_setCurrent[C_tableSize] =      {0, 0.1, 0.2 , 0.3, 0.4, 0.5,  0.6, 0.7,  0.8,  0.9,  1,    1.1,  1.2, 1.3,  1.4};
float A_measuredCurrent[C_tableSize] = {0, 0.2, 0.25, 0.3, 0.4, 0.45, 0.5, 0.55, 0.62, 0.73, 0.82, 0.93, 1  , 1.12, 1.21};


/////////////////////////////////////////// SETUP ////////////////////////////////////////////////////////////////////////////////////////////////////////////////////////////////////////////////////////////////////////////

void setup() {
  delay(10);
  /////////////////////////////////////////// relays
  // relay module1    
  pinMode(PIN_relay1, OUTPUT);
  digitalWrite(PIN_relay1, HIGH);
  pinMode(PIN_relay2, OUTPUT);
  digitalWrite(PIN_relay2, HIGH);
  pinMode(PIN_relay3, OUTPUT);
  digitalWrite(PIN_relay3, HIGH);
  pinMode(PIN_relay4, OUTPUT);
  digitalWrite(PIN_relay4, HIGH);
  // relay module2  
  pinMode(PIN_relay5, OUTPUT);
  digitalWrite(PIN_relay5, HIGH);
  pinMode(PIN_relay6, OUTPUT);
  digitalWrite(PIN_relay6, HIGH);

  /////////////////////////////////////////// EEPROM read
  //EEPROM.put(1, proud);
  //EEPROM.put(6, napeti);

  EEPROM.get(1, proud);
  EEPROM.get(6, napeti);

  //EEPROM.put(1, proud);

  /////////////////////////////////////////// fan control setup

  pinMode(fan2en, OUTPUT);
  analogWrite(fan2en, 255);

  

  pinMode(fan1en, OUTPUT);
  analogWrite(fan1en, 255);


  pinMode(fanEn, OUTPUT);
  digitalWrite(fanEn, HIGH);

  /////////////////////////////////////////// enkoder 1
  pinMode(PIN_DT, INPUT_PULLUP);
  pinMode(PIN_CLK, INPUT_PULLUP);
  pinMode(PIN_BTN1, INPUT_PULLUP);
  lastStateDT = digitalRead(PIN_DT);
  
  /////////////////////////////////////////// enkoder 2
  pinMode(PIN_DT2, INPUT_PULLUP);
  pinMode(PIN_CLK2, INPUT_PULLUP);
  pinMode(PIN_BTN2, INPUT_PULLUP);
  lastStateDT2 = digitalRead(PIN_DT2);
  /////////////////////////////////////////// adc
  Wire.begin();
  ADS.begin();
  ADS.setGain(0);
  /////////////////////////////////////////// vypocty
  initializeResistanceLookup_U();
  initializeResistanceLookup_I();
  
  /////////////////////////////////////////// lcd

  
  lcd.createChar(2, sipka);
  

  delay(10);
  lcd.init();
  lcd.backlight();
  lcd.clear();
  lcd.setCursor(1, 0);
  lcd.print("Laboratorni Zdroj");
  lcd.setCursor(3, 1);
  lcd.print("Smola Antonin");
  lcd.setCursor(12, 3);
  lcd.print("SW:v");
  lcd.setCursor(16, 3);
  lcd.print(programversion);
  // zahájení komunikace po sériové lince
  Serial.begin(9600);
  if (DEBUG) {
    Serial.println();
    Serial.println("DEBUG ENABLED");
  }

  delay(2000);
  lcd.clear();
}

void tikani(int T) {
  unsigned long cas = millis();
  static unsigned long cas_predchozi = 0;
  if (cas - cas_predchozi >= T) {
    tik = HIGH;
    cas_predchozi = cas;
  } else tik = LOW;
}




void loop() {
    
    tikani(refreshrate);
    /*
    currentStateDT = digitalRead(PIN_DT);
    if (currentStateDT != lastStateDT && (millis() - lastDebounceTime) > debounceDelay) {
    lastDebounceTime = millis();  // reset  časovače
    stepCounter++;  

    // pouziti kazdeho druheho kroku
    if (stepCounter % 2 == 0) {
      if (digitalRead(PIN_CLK) != currentStateDT) {// určení směru
        proud--;  // proti směru hodinových ručiček
      } else {
        proud++;  // ve směru hodinových ručiček
      }

      if (proud > 99) {
    proud = 99;
    }
    if (proud < 1) {
    proud = 1;
    }
    lcd.setCursor(0, 0);
    lcd.print("pozice :              ");
    lcd.setCursor(9, 0);
    lcd.print(proud);
    EEPROM.put(1, proud);
    

    
    

    }
  }
  
    lastStateDT = currentStateDT; // ulozeni do pameti
    */

  if (tik) {
    
    
    //nacteni ads hodnot
    int16_t valadc1 = ADS.readADC(1); // proud
    //valadc1 = valadc1 - 116;
    int16_t valadc0 = ADS.readADC_Differential_0_2(); // napeti
    //Serial.println(valadc1);
    //Serial.println(valadc0);
    
    float displvolt = (valadc0 * f ) * 13.1 ;//* 13.269933; // vypocet vysupniho napeti
    float displcur = (valadc1 * f) * 7.1428571429 ;  // because 1 / 0.19 ≈ 5.56 7,1428571429
    //float displcur = (valadc1 * f) * 4.2016806723;
    //float displcur = (valadc1 * f) * 4.6376811594 ; // vypocet vysupniho proudu //0.228
    //Serial.println(displcur);
    //Serial.println(displvolt);
    //Serial.println();
    
    if (displcur < 0) {
      displcur = 0;
    }
    if (DEBUG) {
      Serial.println(displcur);
    }
    displcur = apply_Measured_Current_Correction(displcur);
    if (DEBUG) {
      Serial.println(displcur);
      Serial.println();
    }
    

    if (displcur < 0) {
      displcur = 0;
    }

    if (displvolt < 0) {
      displvolt = 0;
    }

    if (output == 0) {
      displcur = 0;
      displvolt = 0;
    }


    float displpwr = displvolt * displcur;// P=U*I
    if (displpwr < 0) {
    displpwr = 0;
    }


    lcd.setCursor(0, 0);
    lcd.print("U:");
    if (displvolt > 10) {
    lcd.setCursor(2, 0);
    }else {
    lcd.setCursor(2, 0);
    lcd.print(" ");
    lcd.setCursor(3, 0);
    }
    lcd.print(displvolt , 3); 
    lcd.setCursor(8, 0);
    lcd.print("V");


    lcd.setCursor(0, 1);
    lcd.print("I:");

    lcd.setCursor(3, 1);    
    lcd.print(displcur , 3); 
    lcd.setCursor(8, 1);
    lcd.print("A");

    lcd.setCursor(0, 2);
    lcd.print("P:");
    if (displpwr > 10) {
    lcd.setCursor(2, 2);
    }else {
    lcd.setCursor(2, 2);
    lcd.print(" ");
    lcd.setCursor(3, 2);
    }
    lcd.print(displpwr , 3);
    lcd.setCursor(8, 2);
    lcd.print("W");

    lcd.setCursor(10, 0);
    lcd.print("Us:");
     if (napeti > 10) {
    lcd.setCursor(13, 0);
    }else {
    lcd.setCursor(13, 0);
    lcd.print(" ");
    lcd.setCursor(14, 0);
    }
    lcd.print(napeti , 3);
    lcd.setCursor(19, 0);
    lcd.print("V");

    lcd.setCursor(10, 1);
    lcd.print("Is:");
    lcd.setCursor(14, 1);
    lcd.print(proud , 3);
    lcd.setCursor(19, 1);
    lcd.print("A");

    lcd.setCursor(0, 3);
    
    if (output == 0) {
      lcd.print("OUT: OFF");
      analogWrite(fan1en, 0);
      analogWrite(fan2en, 0);
    }else {
      lcd.print("OUT: ON");
      analogWrite(fan1en, 255);
      analogWrite(fan2en, 255);
    }



    lcd.setCursor(11, 3);
    if (output == 0) {
      lcd.print("MODE:N/A");
    }else {
      if (abs(napeti - displvolt) > CCCVmodedifftreshold) {
      lcd.print("MODE: CC");
      }else {
        lcd.print("MODE: CV");
      }

    
    }

    Digipot1.WiperSetPosition(set1);
    
    Digipot2.WiperSetPosition(set2);
    
    Digipot3.WiperSetPosition(set3);
    
    Digipot4.WiperSetPosition(set4);
    
    Digipot5.WiperSetPosition(set5);
    
    Digipot6.WiperSetPosition(set6);
    
    Digipot7.WiperSetPosition(set7);
    
    Digipot8.WiperSetPosition(set8);

     if(DEBUG) {
        Serial.println();
        Serial.print("DCP1 walue =");
        Serial.print(Digipot1.WiperGetPosition());
        

        Serial.println();
        Serial.print("DCP2 walue =");
        Serial.print(Digipot2.WiperGetPosition());
        

        Serial.println();
        Serial.print("DCP3 walue =");
        Serial.print(Digipot3.WiperGetPosition());
        

        Serial.println();
        Serial.print("DCP4 walue =");
        Serial.print(Digipot4.WiperGetPosition());
        

        Serial.println();
        Serial.print("DCP5 walue =");
        Serial.print(Digipot5.WiperGetPosition());
        

        Serial.println();
        Serial.print("DCP6 walue =");
        Serial.print(Digipot6.WiperGetPosition());
        

        Serial.println();
        Serial.print("DCP7 walue =");
        Serial.print(Digipot7.WiperGetPosition());
        

        Serial.println();
        Serial.print("DCP8 walue =");
        Serial.print(Digipot8.WiperGetPosition());
        Serial.println();
        Serial.println();
        Serial.println();
        
        
    }
    
    

  }
    


  int stav_tlacitka = digitalRead(PIN_BTN1);
    static int stav_tlac_predchozi = HIGH;

    
    if (stav_tlacitka == LOW && stav_tlac_predchozi == HIGH && (millis() - lastDebounceTime3) > debounceDelay3) {
      zadani_napeti();
      lastDebounceTime3 = millis();
    }
    stav_tlac_predchozi = stav_tlacitka;



  int stav_tlacitka_2 = digitalRead(PIN_BTN2);
    static int stav_tlac_predchozi_2 = HIGH;

    
    if (stav_tlacitka_2 == LOW && stav_tlac_predchozi_2 == HIGH && (millis() - lastDebounceTime3) > debounceDelay3) {
      zadani_proudu();
      lastDebounceTime3 = millis();
    }
    stav_tlac_predchozi_2 = stav_tlacitka_2;

  
}








void zadani_napeti() {
  disable_output();
  power_DOWN_module1();
  power_DOWN_module2();
  analogWrite(fan1en, 0);
  if (prvnispusteni == 0) {
    analogWrite(fan2en, 255);
  }
    
  lcd.clear();
  int select = 1;
  lastStateDT2 = digitalRead(PIN_DT);
  lastDebounceTime3 = millis();
  while (true) {
    tikani(refreshrate);
  


      currentStateDT2 = digitalRead(PIN_DT);
  if (currentStateDT2 != lastStateDT2 && (millis() - lastDebounceTime2) > debounceDelay2) {
    lastDebounceTime2 = millis();  // reset  časovače
    stepCounter2++;  

    // pouziti kazdeho druheho kroku
    if (stepCounter2 % 2 == 0) {
      if (digitalRead(PIN_CLK) != currentStateDT2) {// určení směru
        
         switch(select){ // proti směru hodinových ručiček
          case 1:
             napeti = napeti - 10;
             break;

          case 2:
             napeti = napeti - 1;
              break;

          case 3:
             napeti = napeti - 0.1;
              break;

          case 4:
             napeti = napeti - 0.01;
              break;

          case 5:
             napeti = napeti - 0.001;
              break;

      }
        if (DEBUG) {
          Serial.print(napeti,3);
          Serial.println("--");
        }
        
        

      } else {

        switch(select){ // proti směru hodinových ručiček
          case 1:
             napeti = napeti + 10;
             break;

          case 2:
             napeti = napeti + 1;
              break;

          case 3:
             napeti = napeti + 0.1;
              break;

          case 4:
             napeti = napeti + 0.01;
              break;

          case 5:
             napeti = napeti + 0.001;
              break;

      }
        if (DEBUG) {
          Serial.print(napeti,3);
          Serial.println("++");
        }
        
      }

        if (napeti > 32) {
          napeti = 32;
       }
         if (napeti < 0) {
          napeti = 0;
        }

      lcd.setCursor(0, 0);
      lcd.print("NAPETI : ");
      if (napeti > 9.999) {
      lcd.setCursor(9, 0);
      }else {
      lcd.setCursor(10, 0);
      }
      lcd.print(napeti); 
      
    

    }
  }

  lastStateDT2 = currentStateDT2; // ulozeni do pameti

    if (tik) {
      
      char formated_napeti[10];  // prevod float na string pro display interkace
      dtostrf(napeti, 6, 3, formated_napeti);  // 6 zanku s 3 desetinymi misty
      if (formated_napeti[0] == ' ') { // detekce mezery na prvnim miste stringu
        formated_napeti[0] = '0';// osetreni aby se cislo 2 netislo 2.000 pak by nesedel ukazatel zvoleneho mista na upravu
      } 

      lcd.setCursor(0, 0);
      lcd.print("NAPETI : ");
      lcd.setCursor(9, 0);
      lcd.print(formated_napeti); 
      
      lcd.setCursor(15, 0);
      lcd.print("V");

    
      lcd.setCursor(0, 1);
    
      switch(select){
      case 1:
        lcd.print("_________");
        lcd.setCursor(9, 1);
        break;

      case 2:
        lcd.print("__________");
        lcd.setCursor(10, 1);
        break;

      case 3:
        lcd.print("____________");
        lcd.setCursor(12, 1);
        break;

      case 4:
        lcd.print("_____________");
        lcd.setCursor(13, 1);
        break;

      case 5:
        lcd.print("______________");
        lcd.setCursor(14, 1);
        break;

      }
      
  
  
      lcd.print("|");
      //lcd.print(char(2));
      lcd.print("                   ");
    


  }
    
    
    

    
    int stlav_tlacitka = digitalRead(PIN_BTN1);
    int stav_tlac_predchozi;

    if (stlav_tlacitka == LOW && stav_tlac_predchozi == HIGH && (millis() - lastDebounceTime3) > debounceDelay3){
      select = select + 1;
      lastDebounceTime3 = millis();
    }
    stav_tlac_predchozi = stlav_tlacitka;




    

    if (select >= 6) {
      power_DOWN_module1();
      power_DOWN_module2();
      lcd.clear();
      lcd.setCursor(5, 1);
      lcd.print("Loading...");
      lcd.setCursor(5, 2);
      lcd.print("Please wait");

      EEPROM.put(6, napeti);

      DESIRED_U = applyVoltageCorrection(napeti);
      DESIRED_I = get_Corrected_Output(proud / 2);

        if(proud < 1.4){
        float input = proud; // Změň hodnotu pro testování
        float corrected = C_apply_Measured_Current_Correction(input);
        float diference = corrected - input;
        DESIRED_I = DESIRED_I + diference;
        if(proud > 0.499 && proud < 0.599){
          DESIRED_I = DESIRED_I - 0.05;
        }else if (proud >= 0.6 && proud < 1.399) {
          DESIRED_I = DESIRED_I - 0.1;
        }
      }else if (proud >= 1.4 && proud <= 5) {
        DESIRED_I = DESIRED_I + 0.1;
      }else if (proud > 5) {
        DESIRED_I = DESIRED_I + 0.15;
        }
        
  
      
      
      
      //DESIRED_I = proud / 2;

      //DESIRED_I = getCorrectedSetValue(proud / 2);
      
      
      /*if (proud > 1.2) {
        DESIRED_I = DESIRED_I + 0.2;
      }*/
      
      vcalc();
      if (prvnispusteni) {
        icalc();
      }
      DCPsetup();
      prvnispusteni = 0;
      goto exit_point;  // Přejdeme na label exit_point a ukončíme funkci
    }
    
    
  }
  exit_point:
  lcd.clear();

}
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

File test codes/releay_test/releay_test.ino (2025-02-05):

#define PIN_relay5 3
#define PIN_relay6 2



#define PIN_relay1 14
#define PIN_relay2 15
#define PIN_relay3 16
#define PIN_relay4 17

#define betweendelay 60

int serparrelaymode = 2; // 0 nic    1 serial    2 paraler

void setup() {
  pinMode(PIN_relay1, OUTPUT);
  digitalWrite(PIN_relay1, HIGH);
  pinMode(PIN_relay2, OUTPUT);
  digitalWrite(PIN_relay2, HIGH);
  pinMode(PIN_relay3, OUTPUT);
  digitalWrite(PIN_relay3, HIGH);
  pinMode(PIN_relay4, OUTPUT);
  digitalWrite(PIN_relay4, HIGH);

  pinMode(PIN_relay5, OUTPUT);
  digitalWrite(PIN_relay5, HIGH);
  pinMode(PIN_relay6, OUTPUT);
  digitalWrite(PIN_relay6, HIGH);
  


}

//PIN_relay5 = napajni modulu 2 (dole)
//PIN_relay6 = napajni modulu 1 (nahore)
//PIN_relay4 = hlavní OUT vypinac

//PIN_relay2 + PIN_relay3 = paraler
//PIN_relay1 = ser

void loop() {
  
  switch (serparrelaymode) {
   case 0:
      digitalWrite(PIN_relay1, HIGH);
      digitalWrite(PIN_relay2, HIGH);
      digitalWrite(PIN_relay3, HIGH);
        break;
   case 1:
      digitalWrite(PIN_relay1, LOW);
      digitalWrite(PIN_relay2, HIGH);
      digitalWrite(PIN_relay3, HIGH);
        break;
   case 2:
      digitalWrite(PIN_relay1, HIGH);
      digitalWrite(PIN_relay2, LOW);
      digitalWrite(PIN_relay3, LOW);
        break;
  }
  
/*
  delay(200);
  digitalWrite(PIN_relay1, LOW);
  delay(betweendelay);
  digitalWrite(PIN_relay1, HIGH);
  delay(betweendelay);
  digitalWrite(PIN_relay1, LOW);
  delay(betweendelay);
  digitalWrite(PIN_relay1, HIGH);
  delay(betweendelay);

  digitalWrite(PIN_relay2, LOW);
  delay(betweendelay);
  digitalWrite(PIN_relay2, HIGH);
  delay(betweendelay);
  digitalWrite(PIN_relay2, LOW);
  delay(betweendelay);
  digitalWrite(PIN_relay2, HIGH);
  delay(betweendelay);

  digitalWrite(PIN_relay3, LOW);
  delay(betweendelay);
  digitalWrite(PIN_relay3, HIGH);
  delay(betweendelay);
  digitalWrite(PIN_relay3, LOW);
  delay(betweendelay);
  digitalWrite(PIN_relay3, HIGH);
  delay(betweendelay);

  digitalWrite(PIN_relay4, LOW);
  delay(betweendelay);
  digitalWrite(PIN_relay4, HIGH);
  delay(betweendelay);
  digitalWrite(PIN_relay4, LOW);
  delay(betweendelay);
  digitalWrite(PIN_relay4, HIGH);
  delay(betweendelay);

  digitalWrite(PIN_relay5, LOW);
  delay(betweendelay);
  digitalWrite(PIN_relay5, HIGH);
  delay(betweendelay);
  digitalWrite(PIN_relay5, LOW);
  delay(betweendelay);
  digitalWrite(PIN_relay5, HIGH);
  delay(betweendelay);

  digitalWrite(PIN_relay6, LOW);
  delay(betweendelay);
  digitalWrite(PIN_relay6, HIGH);
  delay(betweendelay);
  digitalWrite(PIN_relay6, LOW);
  delay(betweendelay);
  digitalWrite(PIN_relay6, HIGH);
  delay(betweendelay);

  digitalWrite(PIN_relay1, LOW);
  digitalWrite(PIN_relay2, LOW);
  digitalWrite(PIN_relay3, LOW);
  digitalWrite(PIN_relay4, LOW);
  digitalWrite(PIN_relay5, LOW);
  digitalWrite(PIN_relay6, LOW);

  delay(5000);

  digitalWrite(PIN_relay1, HIGH);
  digitalWrite(PIN_relay2, HIGH);
  digitalWrite(PIN_relay3, HIGH);
  digitalWrite(PIN_relay4, HIGH);
  digitalWrite(PIN_relay5, HIGH);
  digitalWrite(PIN_relay6, HIGH);*/

}

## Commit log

2025-02-05 kicad libraries
    [100W 30OHM RESISTOR.STEP, 16Bit I2C ADC+PGA - ADS1115.stp, 2x_relay.step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]
2025-02-05 added some files
    [ekonomicka_cast.xlsx, fail schema dmp.kicad_pcb, freerouting.dsn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]
2025-02-18 textova cast
    [ekonomicka_cast.xlsx]
2025-02-21 added dps doc
    [schema dmp.kicad_pcb, schema dmp.kicad_sch]
2025-02-25 added corection to voltage and maybe soved the dcp not found issue
    [DMP2025.ino]
2025-02-25 added 3d files
    [board dmp - front bracket w pcb support.step, board dmp - pcb suport fan.step, board dmp - pcb suport lover L.step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]
2025-02-25 added measured current compensation
2025-02-25 added out cur correction
    [DMP2025.ino]
2025-02-26 added el files
    [fail schema dmp.kicad_pcb, pokus o lepsi usporadani.kicad_pcb, prvni propojeni schema dmp.kicad_pcb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]
2025-02-27 file managemant
    [100W 30OHM RESISTOR.STEP, 16Bit I2C ADC+PGA - ADS1115.stp, 2x_relay.step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]
2025-04-01 bordel removal
    [schema dmp.kicad_pcb, schema dmp3.kicad_pcb]
